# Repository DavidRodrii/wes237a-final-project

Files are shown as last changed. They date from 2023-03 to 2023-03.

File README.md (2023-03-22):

# wes237a-final-project
Final Project for WES237A class, UCSD WES Program, Winter 2023

# Contactless Health Monitoring System

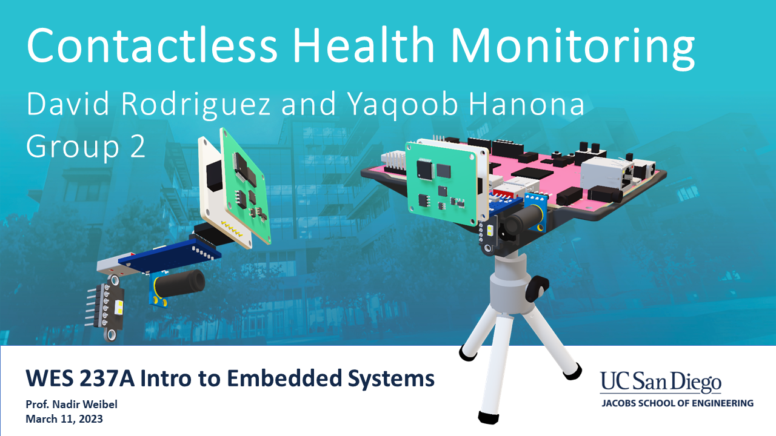
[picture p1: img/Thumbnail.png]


## What does the system do?

- Measures Patient Heart Rate
- Measures Patient Respiratory Activity 
- Measures Patient Temperature
- Detects Human Presence
- Detects Movement of Patient
- Detects Distance away from Patient
- Streams data values to AWS Cloud Server

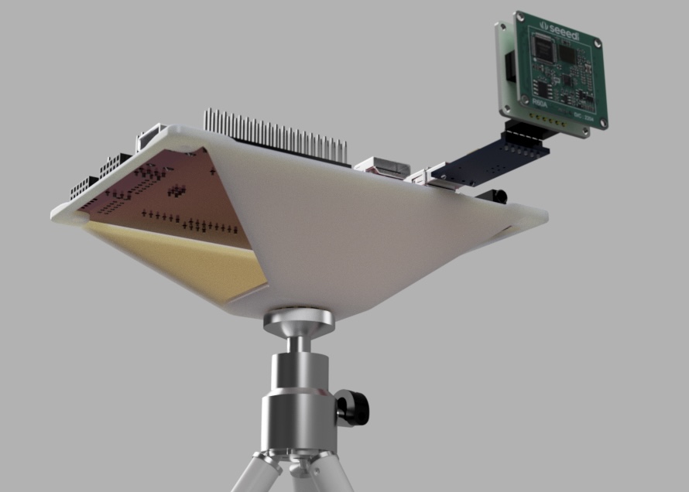
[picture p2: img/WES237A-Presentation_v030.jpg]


## How does it work?

- 60GHz Radar module relies on CWFM Doppler Analysis 
to determine small displacements associated with 
heart beats and breathing.

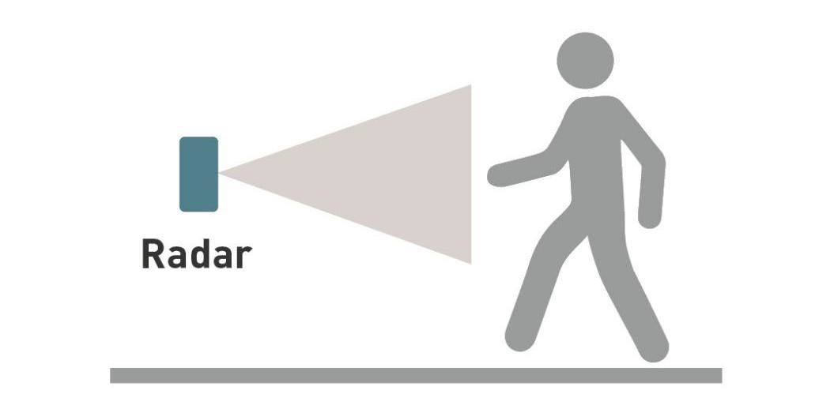
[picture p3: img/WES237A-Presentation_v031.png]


- Infrared Temperature Sensor measures light intensity 
for wavelengths associated with infrared heat signatures.

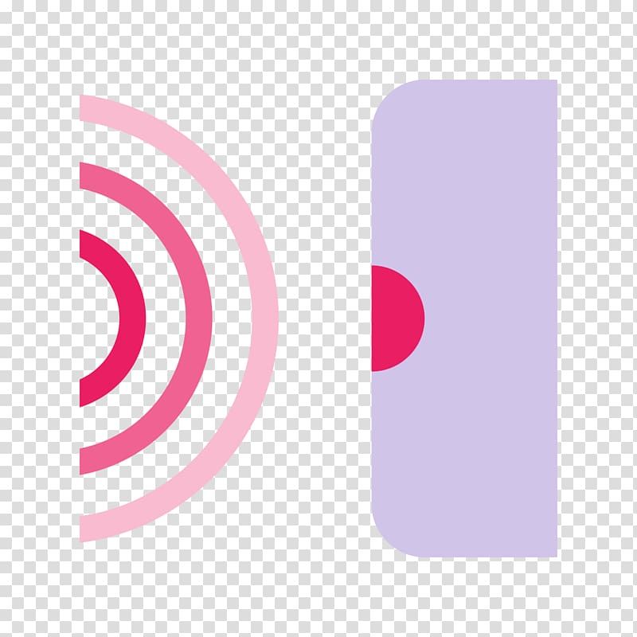
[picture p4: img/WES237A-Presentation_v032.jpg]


- ToF Distance Sensor emits infrared light pulses, records the time
taken to detect reflections, and correlates time to distance value.

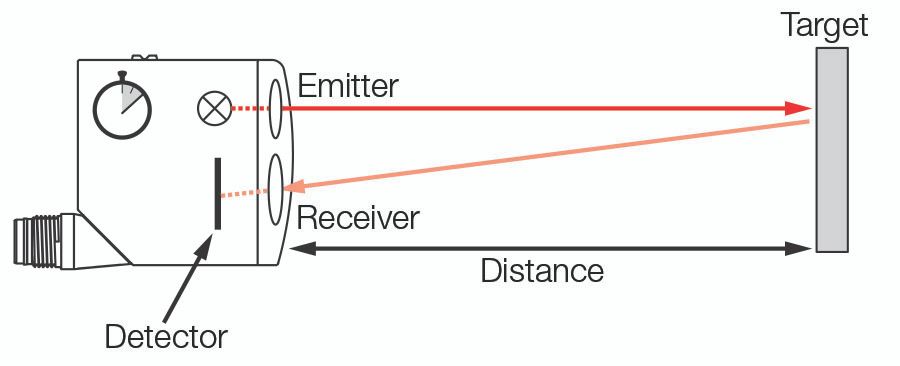
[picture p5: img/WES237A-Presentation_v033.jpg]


- PYNQ Z2 board joins sensor and networking functionality together 
to form a discrete health monitoring device



## Goals
- Create a functional contactless IoT health monitoring system using the Xilinx PYNQ Z2 board.

- Support ability to measure cardio, respiratory, and temperature data at a distance from a patient and produce health metrics visualizations in near real-time.

- Demonstrate and utilize concepts learned in WES 237A lab/lecture.

## WES 237A Topics Used in Project

* **I/O**: Uses PYNQ Microblaze for GPIO Digital Write controls for 
RGB LED Module

* **Multi-Tasking**: Uses Python Multiprocessing library to run multiple 
concurrent data collection and socket connection routines for each 
sensor

* **Networking**: Uses multiple UDP connections and TCP connections to 
send data to Server

* **Sensors/Actuators/IoT**: Uses I2C communication protocol to obtain 
data from VL53L1XV2 ToF Distance and MLX90614ESF Temperature 
sensors

# System Overview

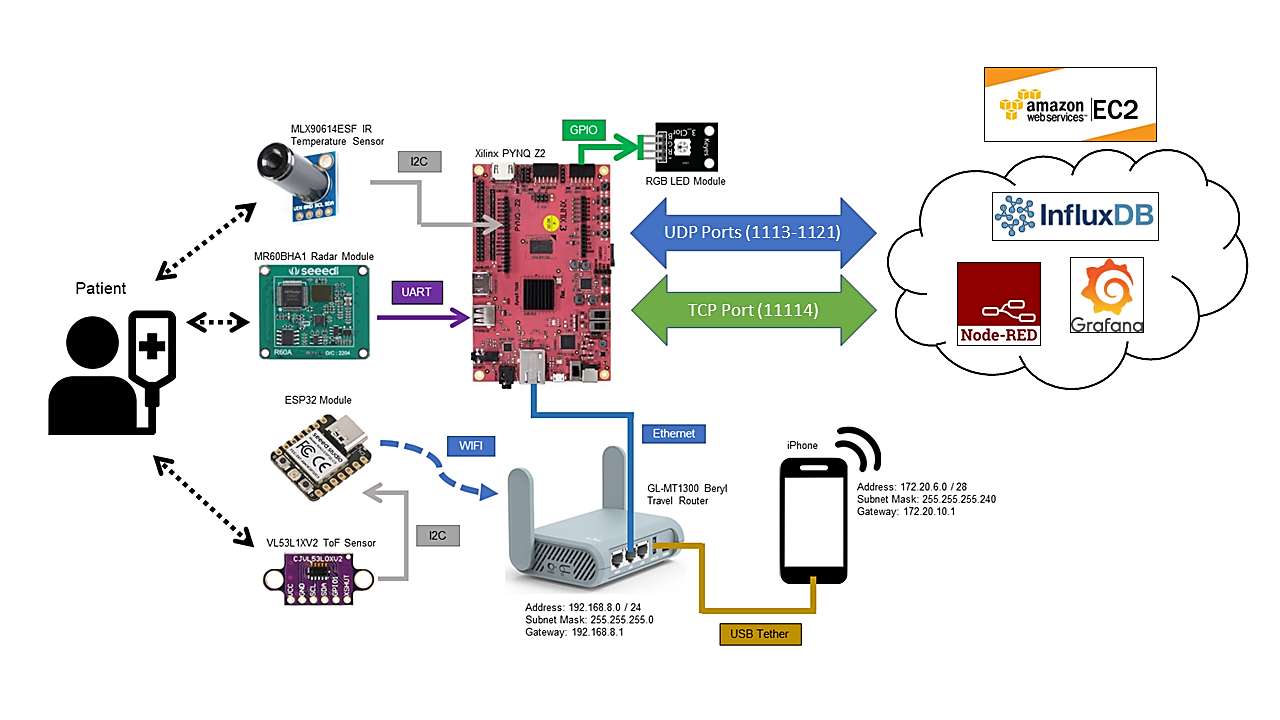
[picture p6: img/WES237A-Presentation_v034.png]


## Components Used

1. Xilinx PYNQ Z2 Board

2. Seeed Studio MR60BHA1 60 GHz mm Wave Sensor 
Onboard MCU processes radar signals and outputs UART messages containing cardio/respiratory health metrics

3. MLX90614 IR Temperature Sensor 
I2C and PWM compatible sensor
Supports measurements taken at 
	distances of ≤12cm

4. VL53L1X ToF Distance Sensor 
I2C compatible sensor
Supports accurate distance measurements 
	of up to 4 meters

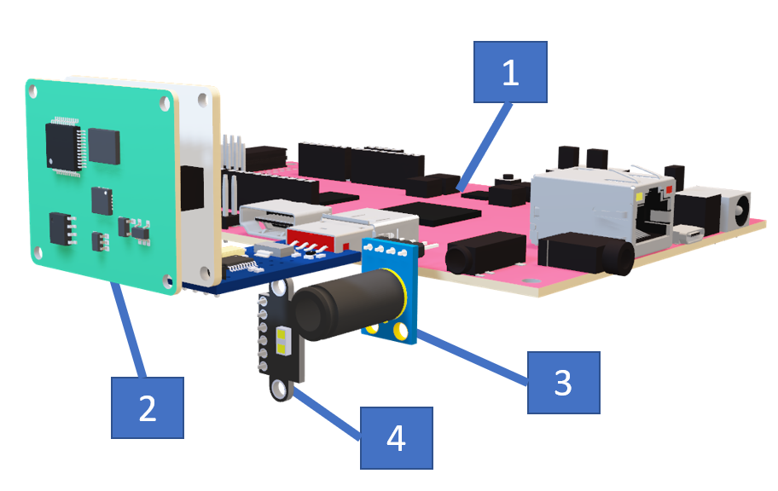
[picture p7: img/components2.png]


# Hardware Schematic
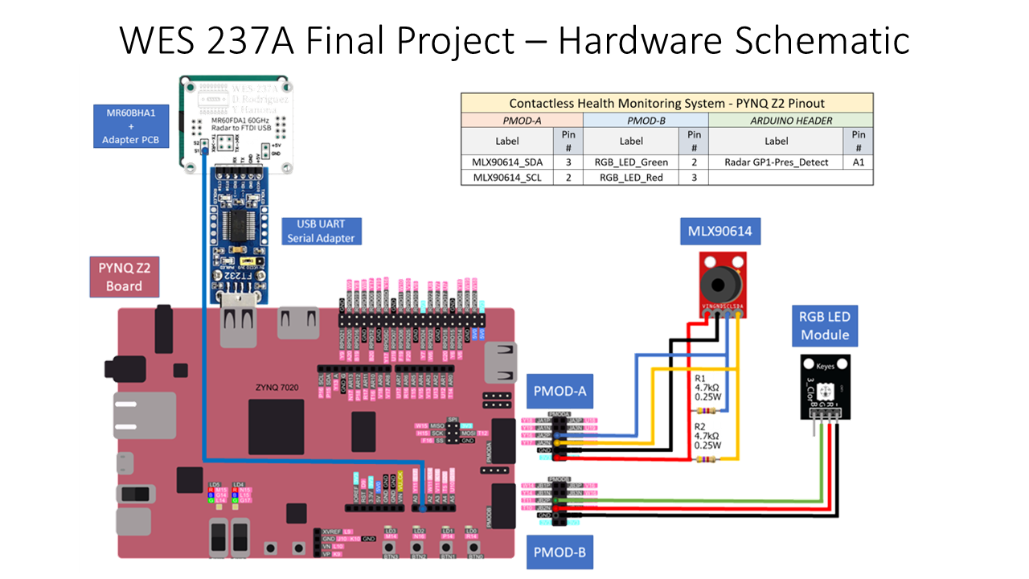
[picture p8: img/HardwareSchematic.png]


## Radar Sensor Assembly - _(Shown Left to Right)_

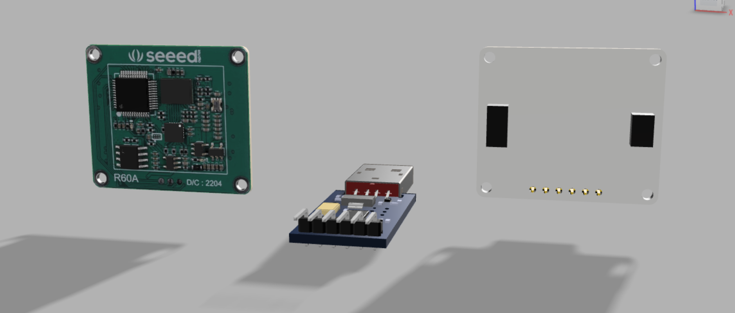
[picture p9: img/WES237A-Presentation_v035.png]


1. Seeed Studio MR60BHA1 60GHz mmWave 
Radar Sensor 

**Note**: MR60BHA1 GP1 Pin IO Pin reports human presence detection via digital signal output (3.3V = Presence Detected / 0V = No Presence Detected)

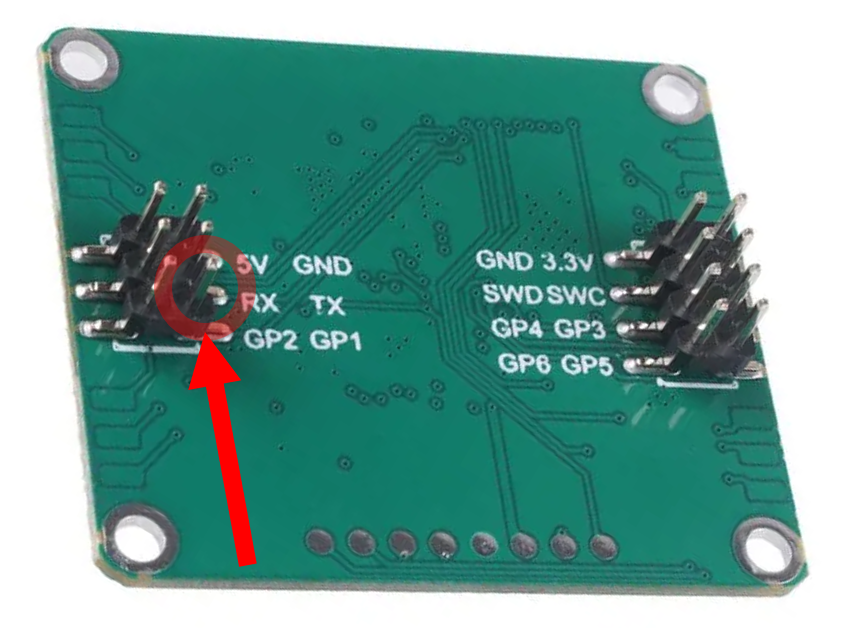
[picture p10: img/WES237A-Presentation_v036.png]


2. USB to UART FTDI Adapter

3. Custom PCB - MR60BHA1-to-USB Adapter

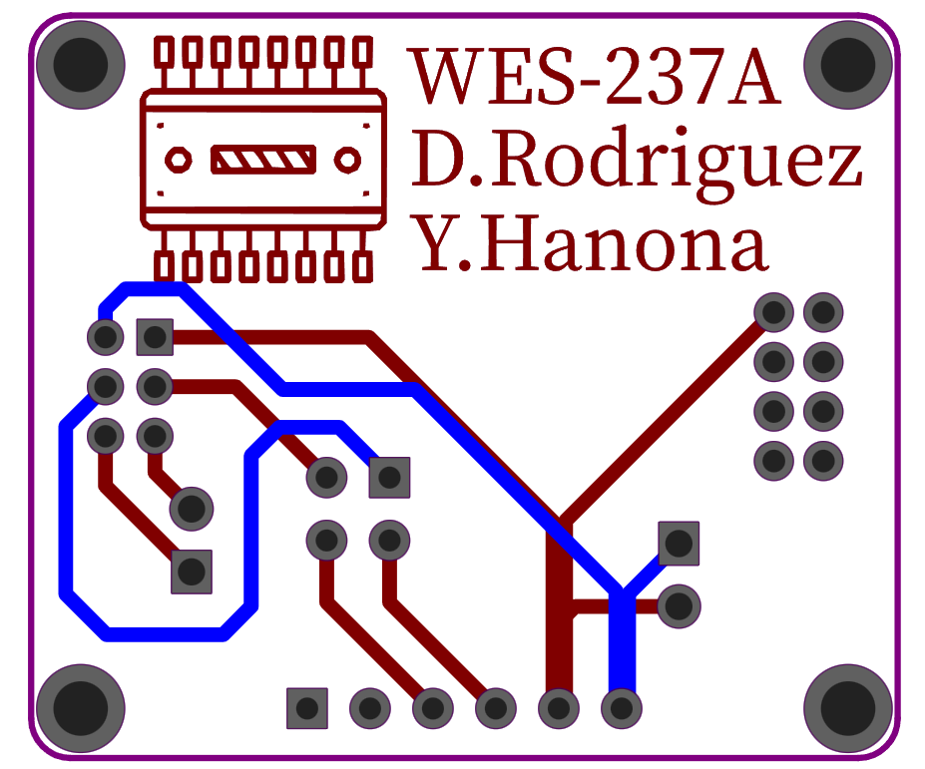
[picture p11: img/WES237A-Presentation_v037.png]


# AWS EC2 Server

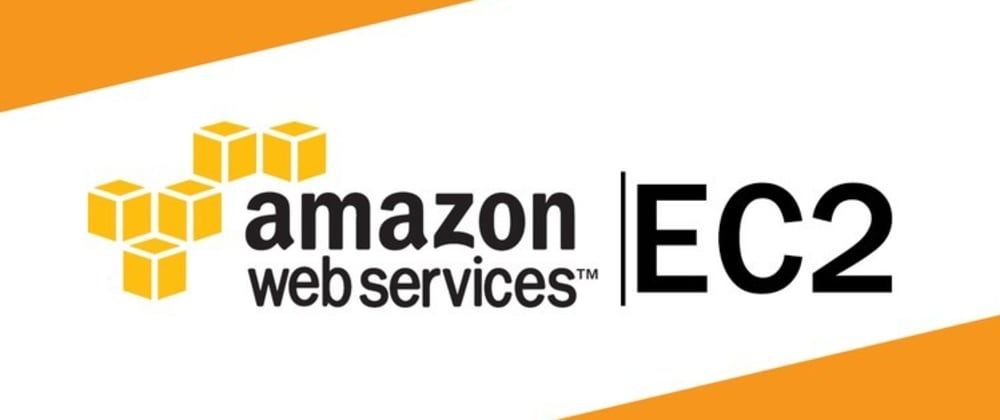
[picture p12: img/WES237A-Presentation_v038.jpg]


## Ubuntu 22.04

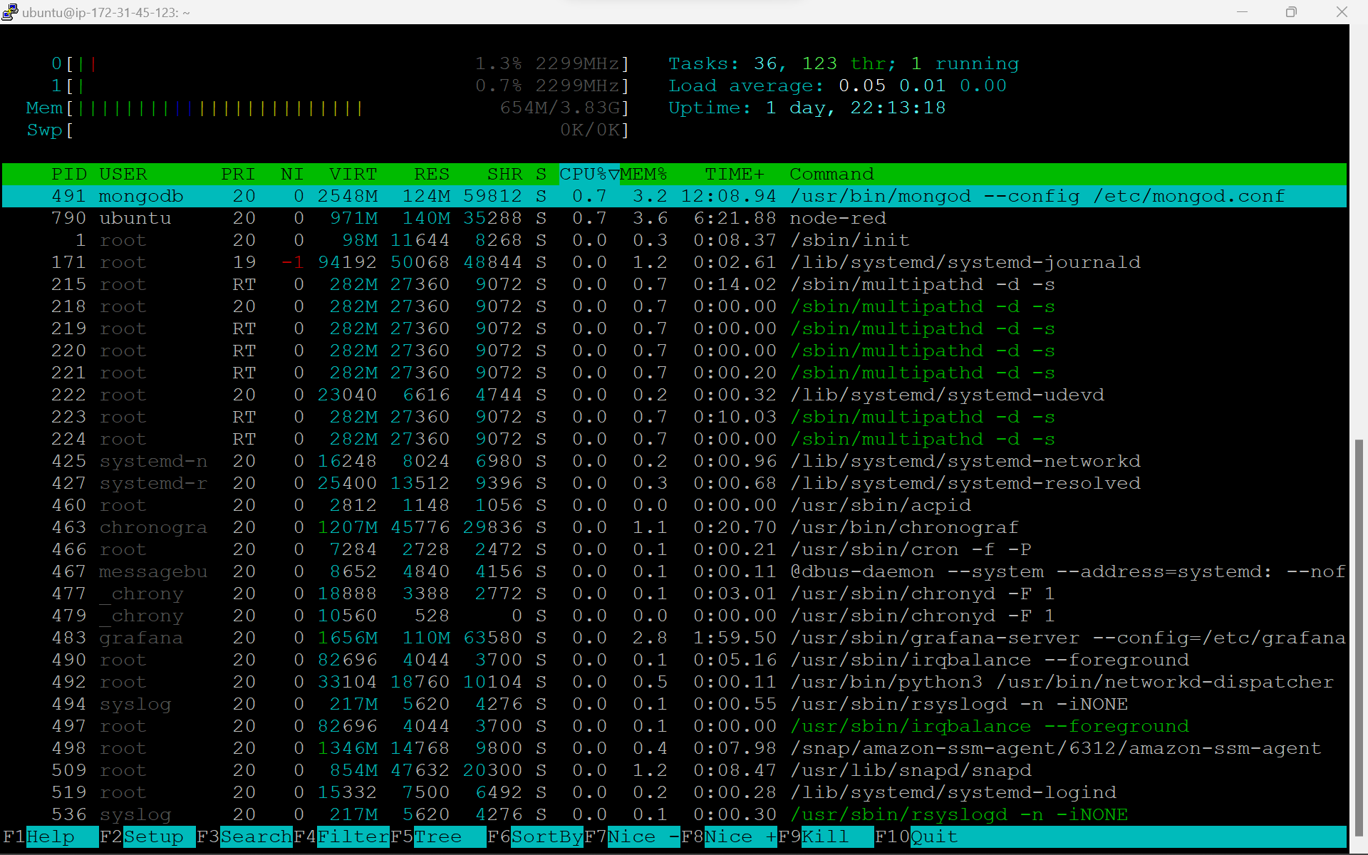
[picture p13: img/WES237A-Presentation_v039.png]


2 Cores vCPU
16 GB EBS Storage

__Services Hosted__:
- NodeRed
- InfluxDB
- Grafana

## NodeRed

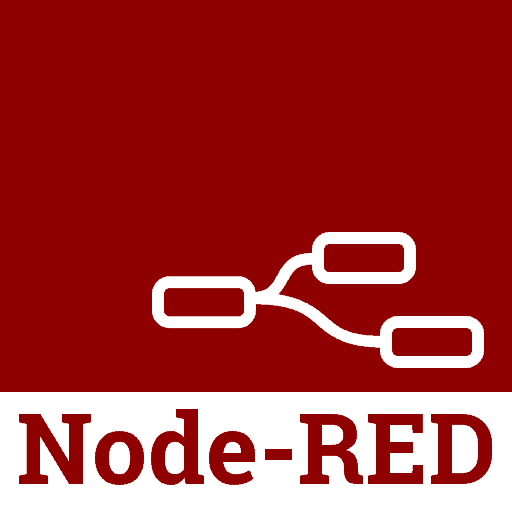
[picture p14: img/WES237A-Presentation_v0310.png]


NodeJS based Flow Process Manager Application that facilitates data flow and network communications using an assortment of node modules:

- Debug Nodes - output data payloads to debug console
- UDP and TCP Port Nodes - host port communications
- HTTP Endpoint Node - supports HTTP-POST requests
- JS Function Nodes - Parse Received Data
- Influxdb Nodes - Forward Data into Database

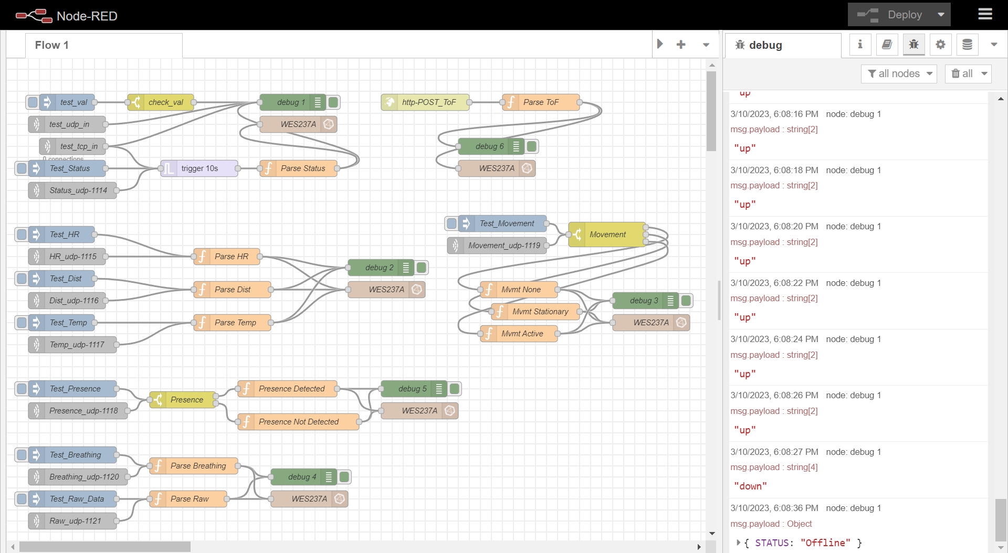
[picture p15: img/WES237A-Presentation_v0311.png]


## Influxdb

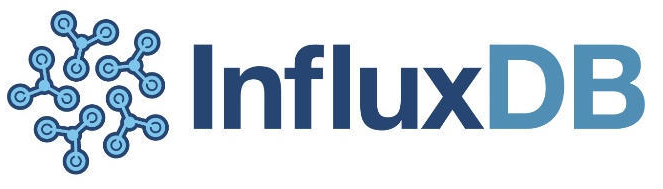
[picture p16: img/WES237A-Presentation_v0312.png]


Open-source Timeseries Database optimized for IoT applications

- Manages Storage of data entries
- Hosts Retention Policy to maintain long-term data accumulation
- Incorporates Timestamp for each data entry
- Accessed by Grafana Service to support dashboard visualization

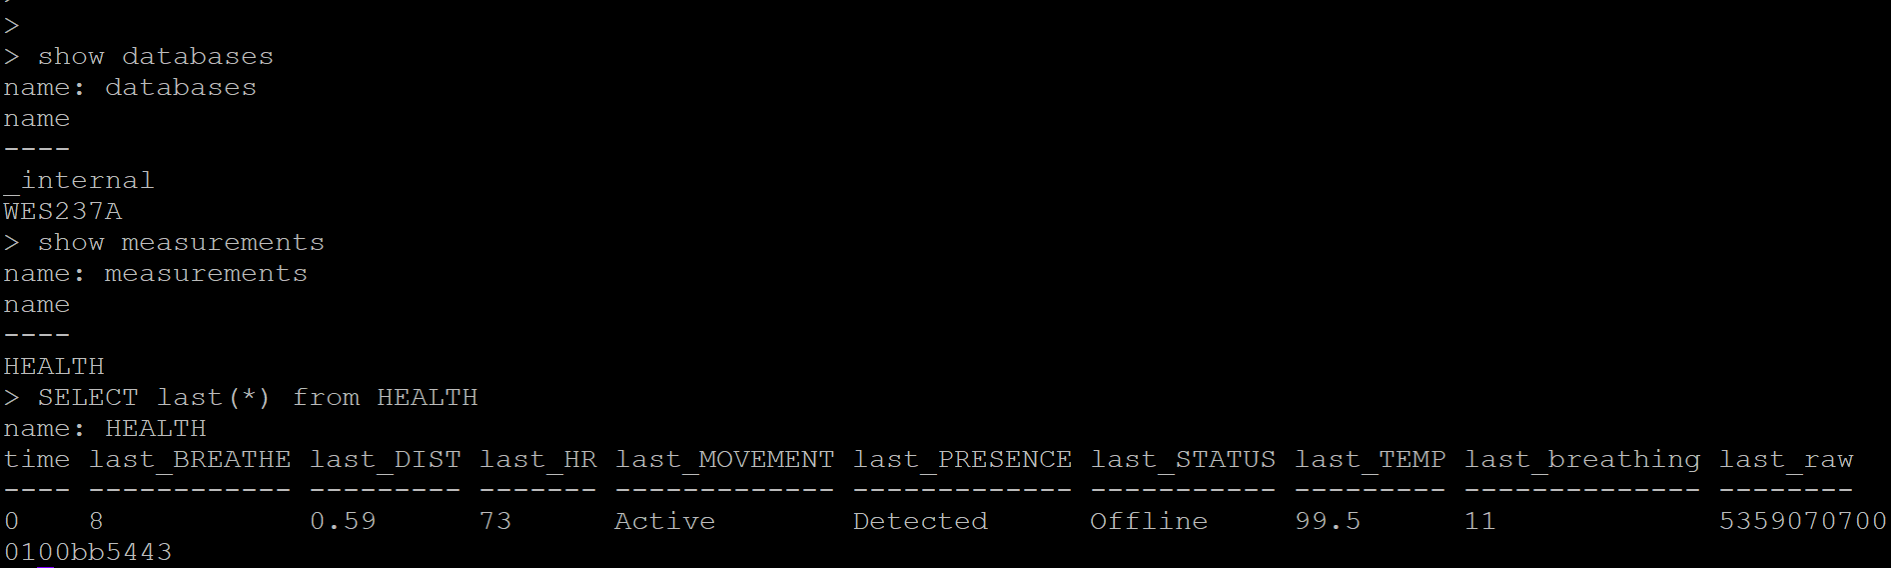
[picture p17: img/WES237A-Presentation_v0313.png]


## Grafana

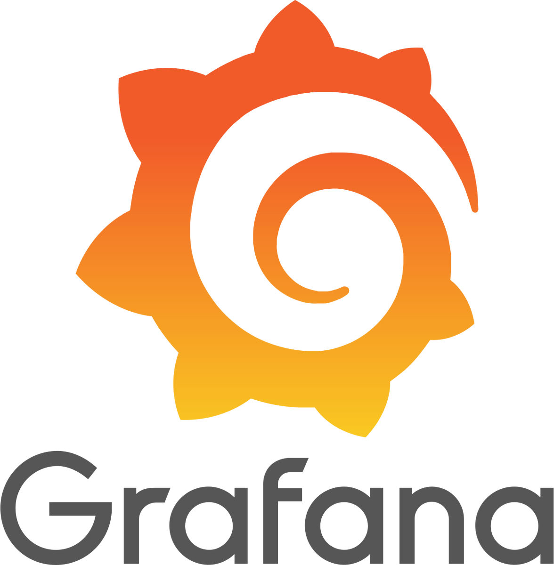
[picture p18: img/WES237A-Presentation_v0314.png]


Data Visualization GUI and Dashboard Application 
Reads and displays sensor data from Influxdb Database

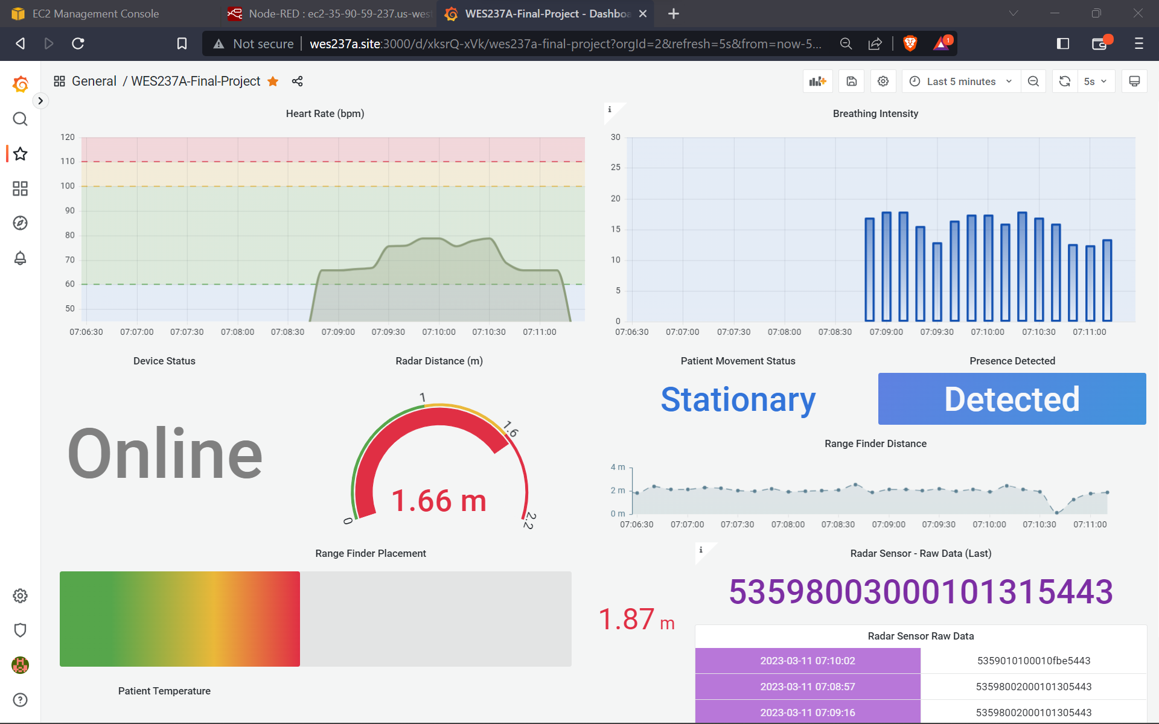
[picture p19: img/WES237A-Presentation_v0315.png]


# Contactless Health Monitor - Multiprocessing Flowchart 
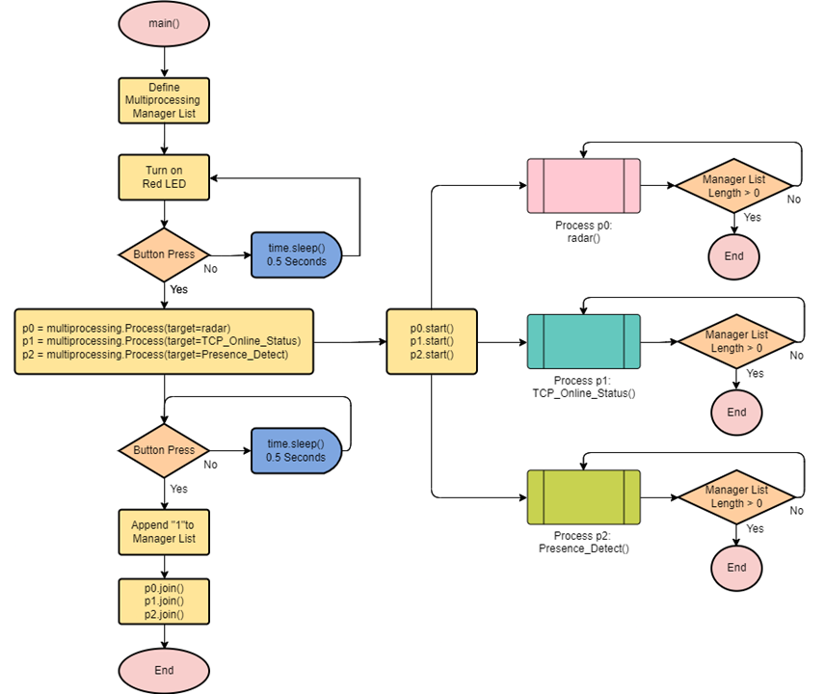
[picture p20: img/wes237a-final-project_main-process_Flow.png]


# Issues

- MLX90614 Temperature Sensor
I2C Reading Errors
‘Errno 9 Socket Error Bad File 
	Descriptor’ with multiprocess

- VL53L1X ToF Distance Sensor Integration
I2C Device Detection Problems

- MR60BHA1 60GHz Radar Sensor 
Intermittent performance of presence
	detection pin 
Serial message querying problems

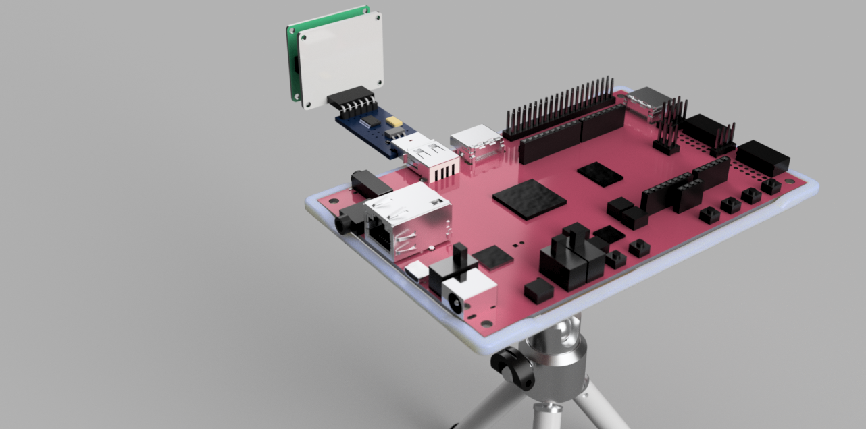
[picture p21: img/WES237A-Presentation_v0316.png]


# Next Steps

1. Spend more time troubleshooting I2C 
write/read steps on MLX90614 
Temperature Sensor

2. Integrate bidirectional communications 
between AWS Server and PYNQ Board

3. Introduce improvements in data filtering 
to improve accuracy

4. Have PYNQ board facilitate Push 
Notifications/Alerts based on health anomaly 
detection

5. Integrate IP Camera stream into Health 
Monitoring System

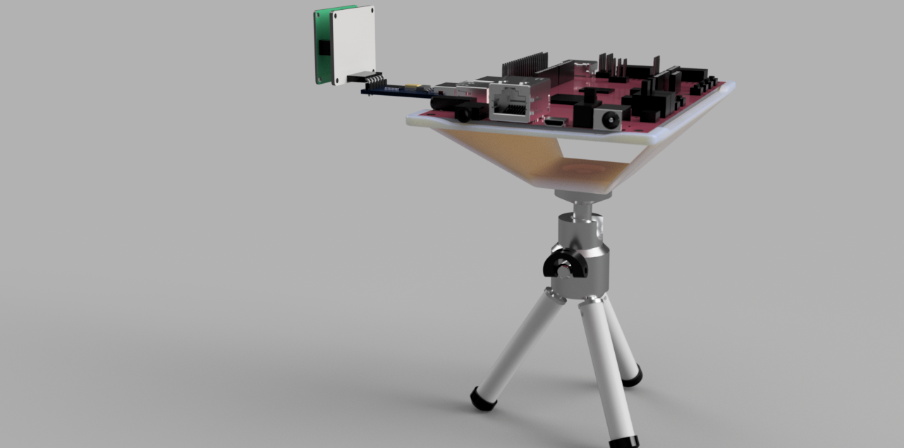
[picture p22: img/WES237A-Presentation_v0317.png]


# Contactless Health Monitoring System Demo

[www\.wes237a\.site:3000](https://www.youtube.com/watch?v=l8WjZGGD_Us)

1\. Login with credentials:

__Username__ : test
    
__Password__ : test

2\. Under  _Dashboards_ \, click on:

__WES237A\-Final\-Project__

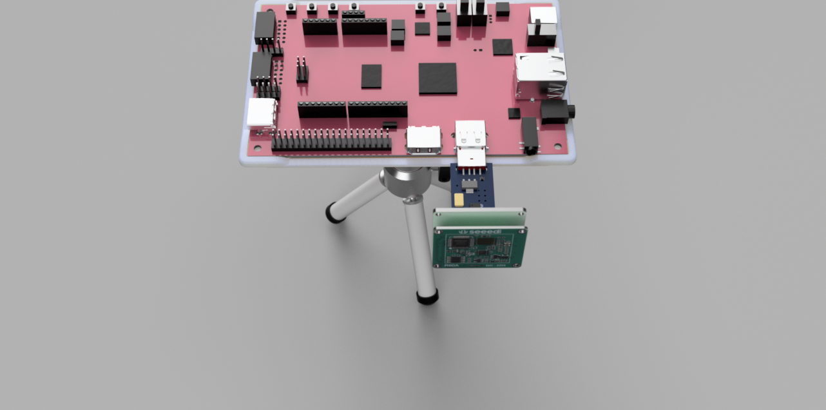
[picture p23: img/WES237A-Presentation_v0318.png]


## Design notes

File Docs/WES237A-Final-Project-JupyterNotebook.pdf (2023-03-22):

# WES-237A Final Project - Contactless Health Monitoring

### David Rodriguez & Yaqoob Hanona

### Group 2

### 11 March 2023

# Part 1: Importing Libraries

# Part 2: Microblaze Functions

In [1]:

import time
import serial
import socket

import subprocess
import multiprocessing
import pynq.lib.rgbled as rgbled
from pynq.overlays.base import BaseOverlay from pynq.lib import MicroblazeLibrary

from pynq.lib.arduino import Arduino_Analog from pynq.lib.arduino import ARDUINO_GROVE_A1
from pynq.lib.arduino import arduino_io

base = BaseOverlay("base.bit")
analog1 = Arduino_Analog(base.ARDUINO,ARDUINO_GROVE_A1)

btns = base.buttons[0:3] # Define list containing all built-in Buttons

In [2]:

%%microblaze base.PMODB
#include "gpio.h"

#include "pyprintf.h"

// Function to turn on/off a selected pin of PMODB int write_gpio(unsigned int pin, unsigned int val){ if (val > 1){
pyprintf("pin value must be 0 or 1");
}
gpio pin_out = gpio_open(pin); gpio_set_direction(pin_out, GPIO_OUT); gpio_write(pin_out, val);
}

// Reset GPIOS function - Resets all PMODB GPIOs (0-7) to Logic LOW void resetGPIOS() {
for (int pin=0; pin < 7; pin++){ // Iterate for all PMODB GPIO Pins write_gpio(pin, 0x00); // calling user defined function
}
}

void setGreen_HIGH(){
write_gpio(2, 0x01);
}

void setGreen_LOW(){
write_gpio(2, 0x00);
}

void setRed_HIGH(){
write_gpio(3, 0x01);
}

void setRed_LOW(){
write_gpio(3, 0x00);
}

# Part 3: Reset GPIOs

# Part 4: Defining Multiprocessing Processes

In [3]:

resetGPIOS() # Reset all GPIOs

In [4]:

setGreen_LOW() # Turn Green LED Off setRed_LOW() # Turn Red LED Off

In [5]:

# WES237A Final Project - Multiprocessing Processes

# Define Multiprocssing Manager List

manager = multiprocessing.Manager() seq_complete_list = manager.list()

setRed_HIGH() # Turn Red LED On = "Not Connected"

serverName = 'ec2-35-90-59-237.us-west-2.compute.amazonaws.com' # AWS Server Public DNS Domain testUDP_Port = 1113 # TEST UDP Port

clientPort = 11114 # TCP Client Port
port = 11115 # AWS Server TCP Listening Port

def Presence_Detect(): # Gets Presence Detection status from Radar Sensor GP1 Pin voltage, # then reports status to AWS Server via UDP Connection
serverName = 'ec2-35-90-59-237.us-west-2.compute.amazonaws.com' # AWS Server Public DNS UDPclientPort = 1118
clientSocket = socket.socket(family=socket.AF_INET, type=socket.SOCK_DGRAM)
while True:
analog1.read()
bits = analog1.read('raw')[1]
if bits >= 1000:
message = '1'
else:
message = '0'
time.sleep(0.05)
print('sending message: {}'.format(message))
# Connect to AWS Server UDP Port and Send Data clientSocket.sendto(message.encode(),(serverName, UDPclientPort)) time.sleep(9)

if len(seq_complete_list) > 0:
break
clientSocket.close()

def TCP_Online_Status(): # Report Online Status to AWS Server via TCP Connection # Create a TCP/IP socket
c_sock = socket.socket(socket.AF_INET, socket.SOCK_STREAM) print('Connecting PYNQ Client. . .')

# Connect Client

c_sock.connect((serverName, clientPort))
print('Connected to AWS Server!')

setRed_LOW() # Turn Red LED Off setGreen_HIGH() # Turn Green LED On

upMessage = 'up'
downMessage = 'down'

while True:
setGreen_HIGH()
time.sleep(8)
c_sock.send(upMessage.encode())

if len(seq_complete_list) > 0: setGreen_LOW()
setRed_HIGH()
# Send AWS TCP Server Offline Message c_sock.send(downMessage.encode()) break

# Disconnect from Client

c_sock.close()
print('Client Connection Socket Closed!')

def radar():
presence_detect = 0
while True:
serMsg = serial.Serial('/dev/ttyUSB0', 115200, timeout=2) #serMsg.flushInput()

# Read Radar Data from serial port

ch = serMsg.read(15).hex() # 15 bytes = max frame size for radar module

FRAME_HEADER = '5359'
END_OF_FRAME = '5443'

pt1 = ch.split(FRAME_HEADER)[1] pt2 = pt1.split(END_OF_FRAME)[0]

control_word = pt2[0:2]
command_word = pt2[2:4]
data_len = int(pt2[4:8])
data = pt2[8:(9+data_len)]

value_list = []

# Segment Data based on individual Bytes if data_len == 1:

value = int(data, base=16) value_list.append(value)
else:
for i in range(0, data_len):
value_segment = str(data[i]) + str(data[i+1]) value = int(value_segment, base=16) value_list.append(value)

# Heart Rate Value

if control_word == '85':
measurement_type = 'HR' # Heart Rate
if command_word == '02':
print('Heart Rate Values: ', value_list)
# Connect to AWS Server UDP Port and Send Data

clientSocket = socket.socket(family=socket.AF_INET, type=socket.SOCK_DGRAM) clientSocket.sendto(str(value_list[0]).encode(),(serverName, 1115)) clientSocket.close()
elif command_word == '05':
print('Heart Rate Waveform: ', value_list)

# Respiratory Intensity Value

if control_word == '81':
measurement_type = 'RM' # Respiratory Monitoring if command_word == '02':
print('Breathing Waveform: ', value_list)
# Connect to AWS Server UDP Port and Send Data

clientSocket = socket.socket(family=socket.AF_INET, type=socket.SOCK_DGRAM) clientSocket.sendto(str(value_list[0]).encode(),(serverName, 1120)) clientSocket.close()

elif command_word == '01':
print('Breathing Values: ', value_list)

# Human Presence Status, Distance, and Movement Info if control_word == '80':

measurement_type = 'HP' # Human Presence Info
movement = ''

# Human Presence Status

# NOTE: Although this is redundant to include since Presence_Detect() function fulfills the same purpose,

# this UDP transmission is only enacted if the Human Presence parameter is detected in the Raw Radar data stream if command_word == '01':

# Presence Status has changed

if value == 1:
print('Presence Detected!') message = '1'
else:
message = '0'
print('Presence Not Detected!')
clientSocket = socket.socket(family=socket.AF_INET, type=socket.SOCK_DGRAM) clientSocket.sendto(message.encode(),(serverName, 1118)) clientSocket.close()

# Human Movement Status

if command_word == '02':

# Part 5: Health Monitoring Program

print('Human Movement Info: ', value_list) if (int(value_list[0]) == 2):
movement = 'Active'
movement_status = '02'
elif (int(value_list[0]) == 1): movement = 'Stationary'
movement_status = '01'
else:
movement = 'None'
movement_status = '00'
if (len(value_list) == 0): movement = 'None'
movement_status = '00'
print('Movement Status: ', movement)
# Connect to AWS Server UDP Port and Send Data

clientSocket = socket.socket(family=socket.AF_INET, type=socket.SOCK_DGRAM) clientSocket.sendto(movement_status.encode(),(serverName, 1119)) clientSocket.close()

# Radar Distance Value

if command_word == '04':
print('Human Distance Info (cm): ', int(pt2[10:12],base=16))
# Connect to AWS Server UDP Port and Send Data

clientSocket = socket.socket(family=socket.AF_INET, type=socket.SOCK_DGRAM) clientSocket.sendto(str(int(pt2[10:12],base=16)).encode(),(serverName, 1116)) clientSocket.close()

# Send Raw Data from Radar Module

raw_data = FRAME_HEADER + pt2 + END_OF_FRAME
# Connect to AWS Server UDP Port and Send Raw Data

clientSocket = socket.socket(family=socket.AF_INET, type=socket.SOCK_DGRAM) clientSocket.sendto(str(raw_data).encode(),(serverName, 1121)) clientSocket.close()

serMsg.close()
time.sleep(0.005)

if len(seq_complete_list) > 0: break

In [6]:

# Define Main Program

def main():
setRed_HIGH() # Turn Red LED On

print('Press Button to initialize Health Monitoring System') while True:
if btns.read() != 0:
time.sleep(0.5)
# Initialize Processes

print('Initializing Processes') break

# Create 3 Processes

p0 = multiprocessing.Process(target=radar)
p1 = multiprocessing.Process(target=TCP_Online_Status) p2 = multiprocessing.Process(target=Presence_Detect)

# Start all Processes

p0.start()
p1.start()
p2.start()

while True:
if btns.read() != 0:
time.sleep(0.5)
seq_complete_list.append(1) setRed_LOW() # Red LED off
setGreen_LOW() # Green LED off
break

time.sleep(2) # Allow sufficient time for socket connections to close

# Join & Close all Processes

p0.join()
p0.close()

Press Button to initialize Health Monitoring System Initializing Processes
Connecting PYNQ Client. . .
sending message: 0
Connected to AWS Server!
Heart Rate Values: [81]
Human Distance Info (cm): 35 Human Movement Info: [1]
Movement Status: Stationary Human Distance Info (cm): 35 Human Movement Info: [2]
Movement Status: Active
Breathing Waveform: [9]
Heart Rate Values: [83]
Human Distance Info (cm): 35 sending message: 0
Heart Rate Values: [83]
Breathing Waveform: [9]
Human Distance Info (cm):
35Heart Rate Values: [83]
Human Distance Info (cm): 35 Heart Rate Values: [83]
Breathing Waveform:
[9]Human Distance Info (cm): 35sending message: 0
Heart Rate Values:
[83]Human Distance Info (cm): 35 Client Connection Socket Closed! Sequence Stopped!

p1.join()
p1.close()
p2.join()
p2.close()

setRed_LOW() # Red LED off setGreen_LOW() # Green LED off

print('Sequence Stopped!')

if __name__ == '__main__':
main()

In [ ]:

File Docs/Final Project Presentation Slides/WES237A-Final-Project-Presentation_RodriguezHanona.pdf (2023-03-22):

# Contactless Health Monitoring

## David Rodriguez and Yaqoob Hanona

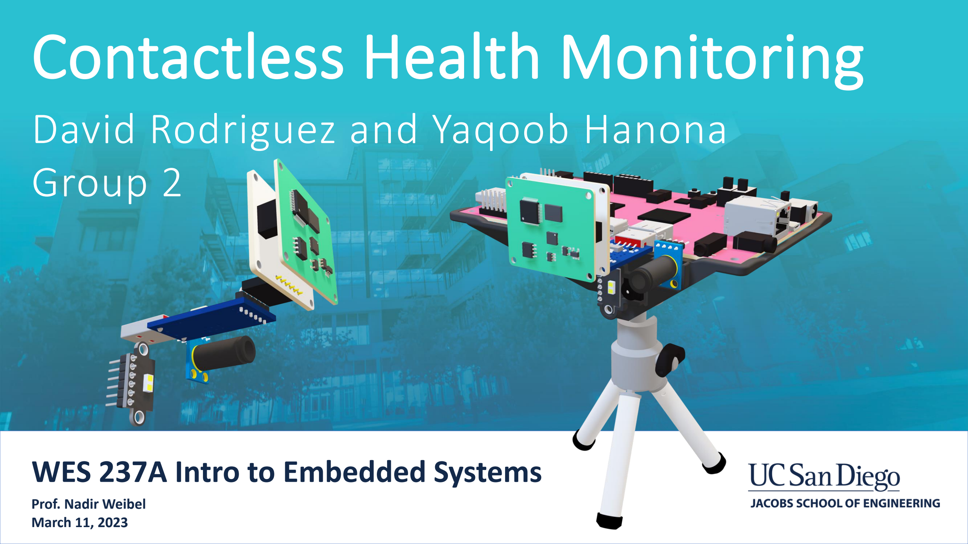
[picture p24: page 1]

Prof. Nadir Weibel
March 11, 2023

WES 237A Intro to Embedded Systems

## Group 2

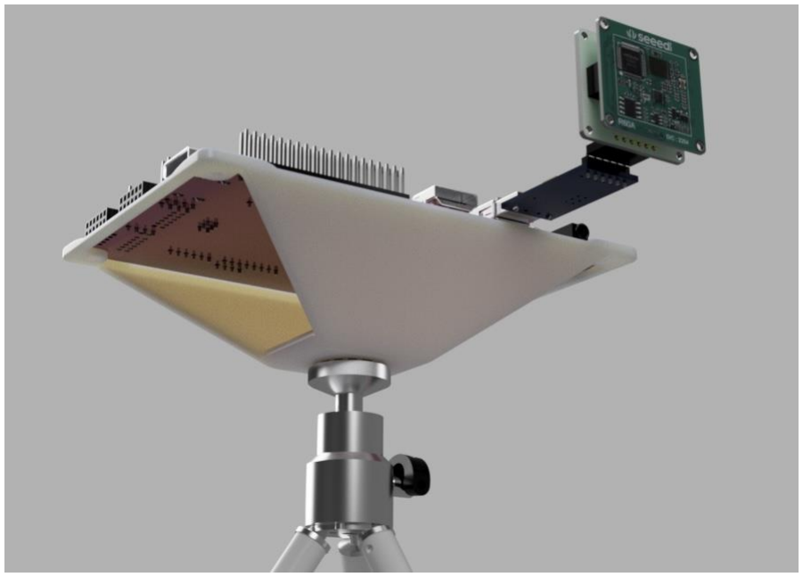
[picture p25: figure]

COMPUTER SCIENCE AND ENGINEERING | WES 237A Winter 2023 – Group 2

## CONTACTLESS HEALTH MONITORING SYSTEM

- What does the system do?
- Measures Patient Heart Rate
- Measures Patient Respiratory
Activity
- Measures Patient Temperature
- Detects Human Presence
- Detects Movement of Patient
- Detects Distance away from Patient
- Streams data values to AWS Cloud Server

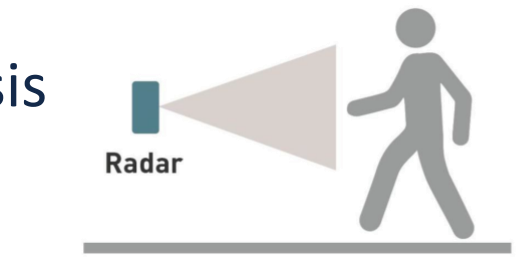
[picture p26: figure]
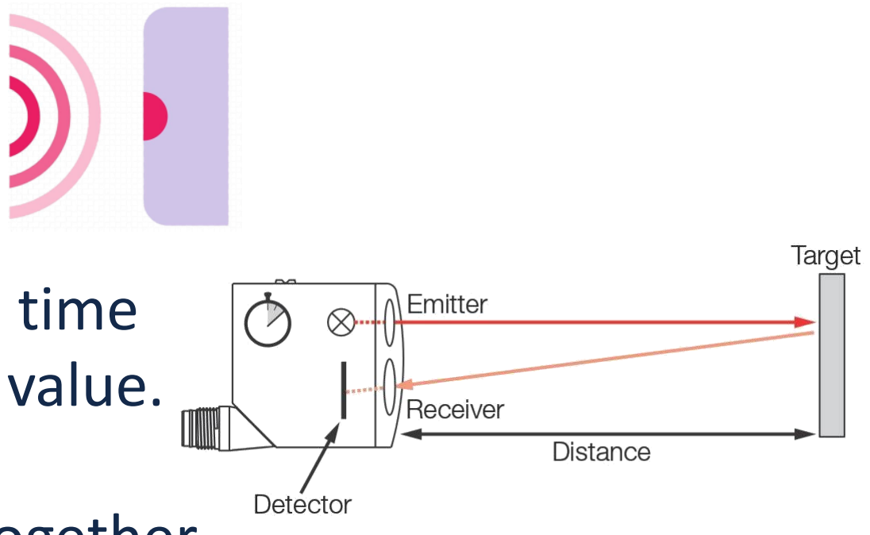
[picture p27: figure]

COMPUTER SCIENCE AND ENGINEERING | WES 237A Winter 2023 – Group 2

## CONTACTLESS HEALTH MONITORING SYSTEM

- How does it work?

60GHz Radar module relies on CWFM Doppler Analysis
to determine small displacements associated with heart beats and breathing.

Infrared Temperature Sensor measures light intensity
for wavelengths associated with infrared heat signatures.

ToF Distance Sensor emits infrared light pulses, records the time taken to detect reflections, and correlates time to distance value.

PYNQ Z2 board joins sensor and networking functionality together to form a discrete health monitoring device

COMPUTER SCIENCE AND ENGINEERING | WES 237A Winter 2023 – Group 2

## CONTACTLESS HEALTH MONITORING SYSTEM

- Goals
- Create a functional contactless IoT health monitoring system using the Xilinx PYNQ Z2 board.
- Able to measure cardio, respiratory, and temperature data at a distance from a patient and produce health metrics visualizations in near real-time.
- Able to use concepts learned in WES 237A lab/lecture.

COMPUTER SCIENCE AND ENGINEERING | WES 237A Winter 2023 – Group 2

## WES 237A TOPICS USED IN PROJECT

- I/O: Uses PYNQ Microblaze for GPIO Digital Write controls for
RGB LED Module
- Multi-Tasking: Uses Python Multiprocessing library to run multiple concurrent data collection and socket connection routines for each sensor
- Networking: Uses multiple UDP connections and TCP connections to send data to Server
- Sensors/Actuators/IoT: Uses I2C communication protocol to obtain data from VL53L1XV2 ToF Distance and MLX90614ESF Temperature sensors

## SYSTEM OVERVIEW

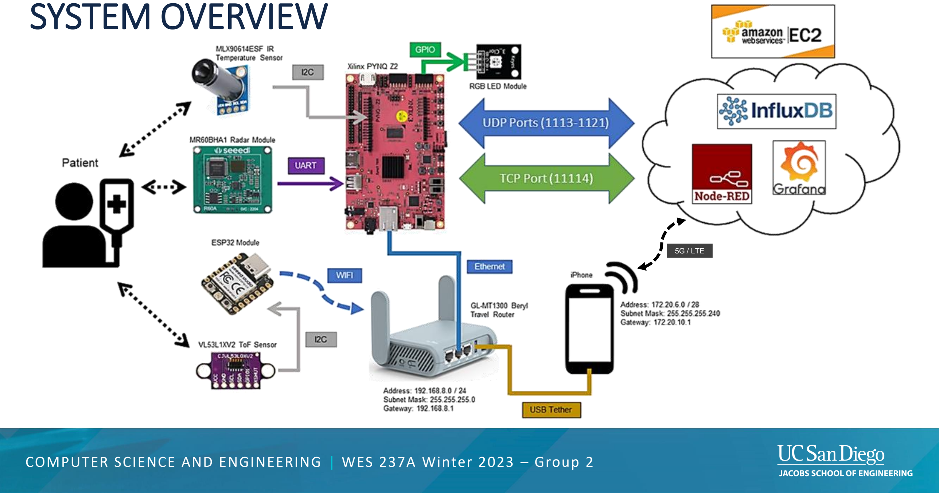
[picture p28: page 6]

COMPUTER SCIENCE AND ENGINEERING | WES 237A Winter 2023 – Group 2

5G / LTE

# COMPONENTS USED

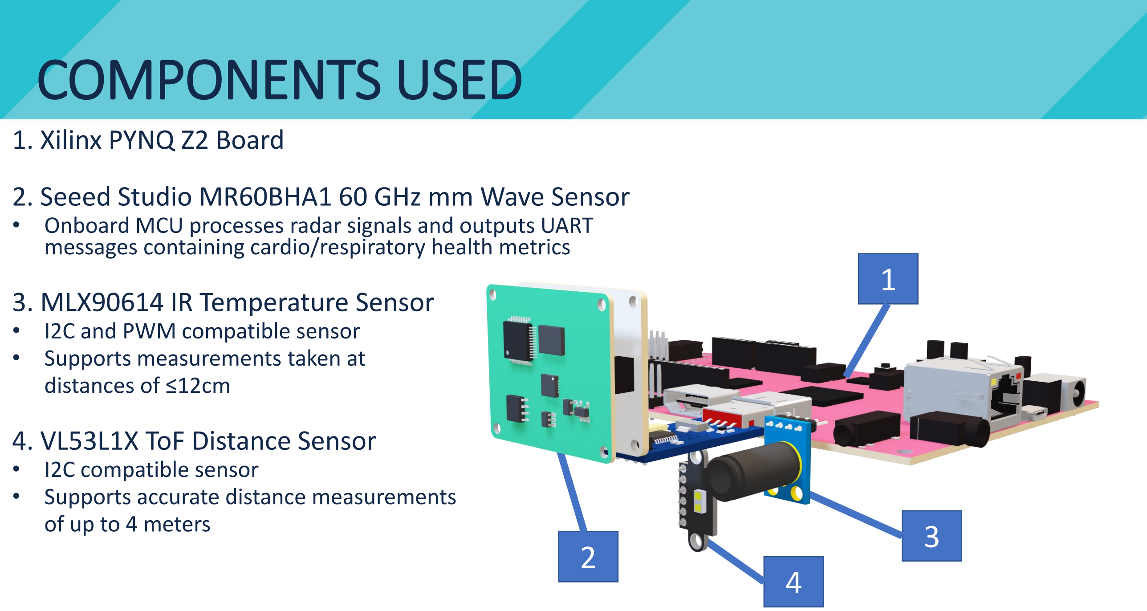
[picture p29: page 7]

1. Xilinx PYNQ Z2 Board
2. Seeed Studio MR60BHA1 60 GHz mm Wave Sensor
- Onboard MCU processes radar signals and outputs UART messages containing cardio/respiratory health metrics
3. MLX90614 IR Temperature Sensor
- I2C and PWM compatible sensor
- Supports measurements taken at
distances of ≤12cm
4. VL53L1X ToF Distance Sensor
- I2C compatible sensor
- Supports accurate distance measurements of up to 4 meters
2

3
4

1

# RADAR SENSOR ASSEMBLY

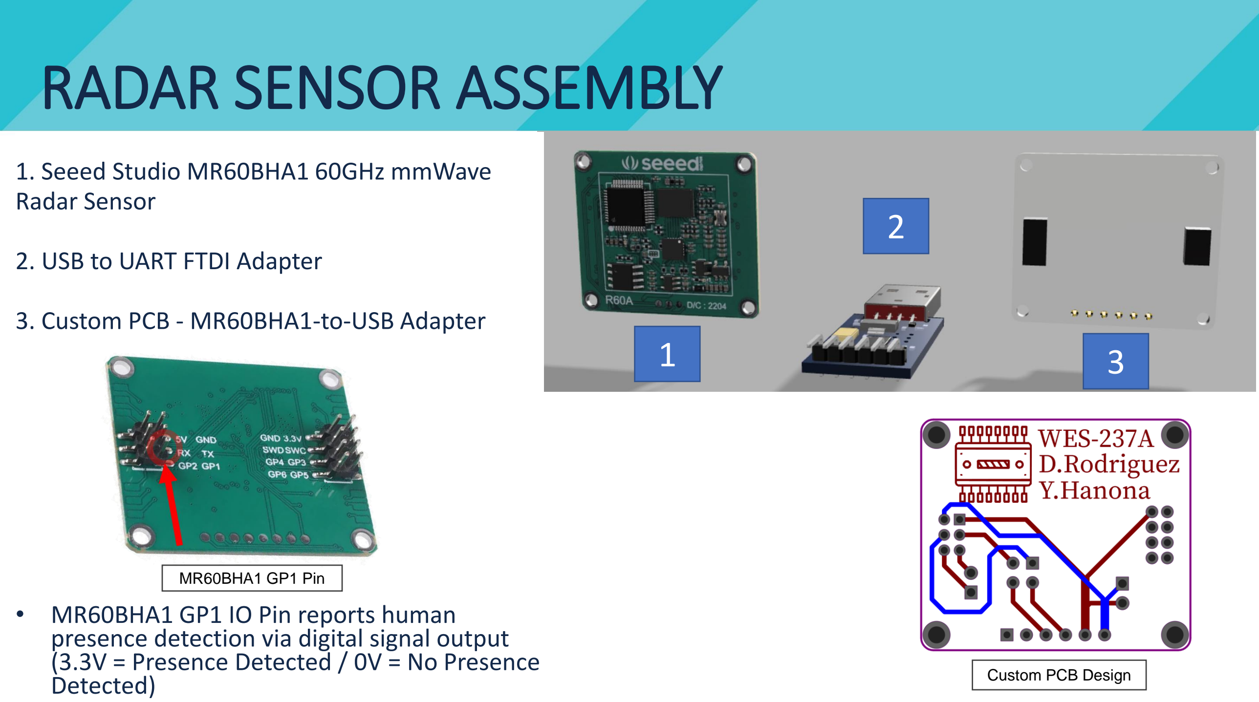
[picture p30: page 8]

1. Seeed Studio MR60BHA1 60GHz mmWave Radar Sensor
2. USB to UART FTDI Adapter
3. Custom PCB - MR60BHA1-to-USB Adapter
- MR60BHA1 GP1 IO Pin reports human presence detection via digital signal output (3.3V = Presence Detected / 0V = No Presence Detected)

1

2

3

MR60BHA1 GP1 Pin

Custom PCB Design

# AWS EC2 SERVER

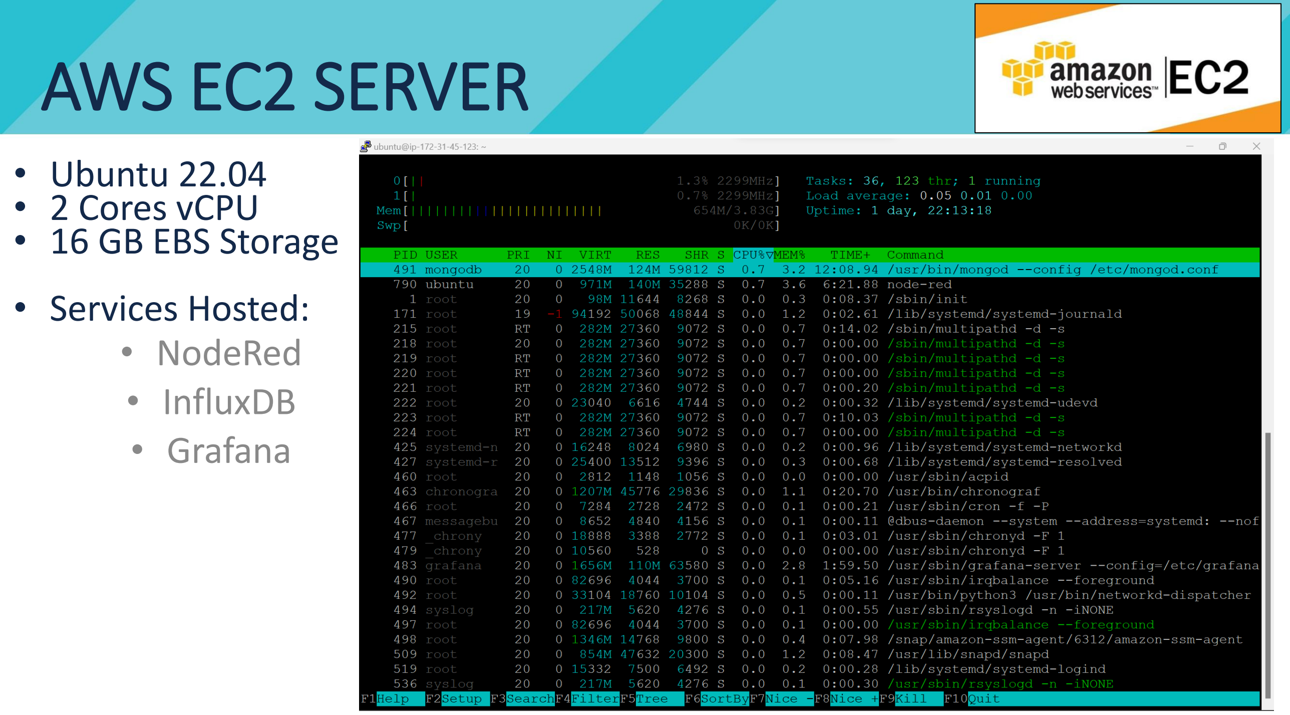
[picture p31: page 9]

- Ubuntu 22.04
- 2 Cores vCPU
- 16 GB EBS Storage
- Services Hosted:
- NodeRed
- InfluxDB
- Grafana

# AWS EC2 SERVER: NODERED

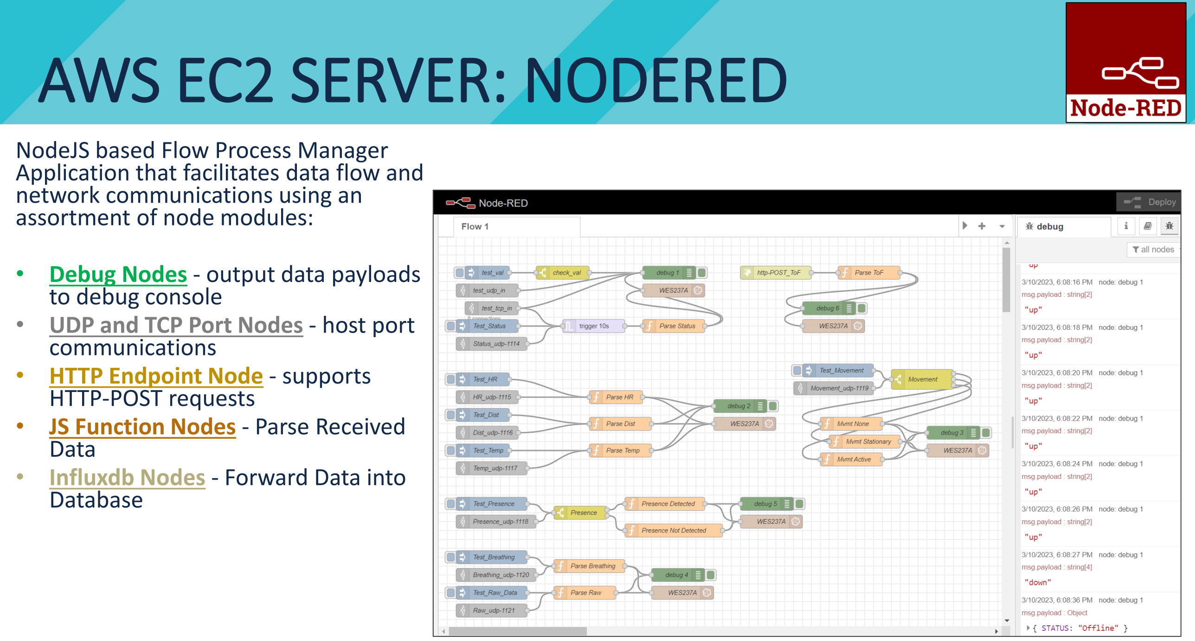
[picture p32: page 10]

NodeJS based Flow Process Manager Application that facilitates data flow and network communications using an assortment of node modules:

- Debug Nodes - output data payloads to debug console
- UDP and TCP Port Nodes - host port communications
- HTTP Endpoint Node - supports HTTP-POST requests
- JS Function Nodes - Parse Received Data
- Influxdb Nodes - Forward Data into Database

# AWS EC2 SERVER: INFLUXDB

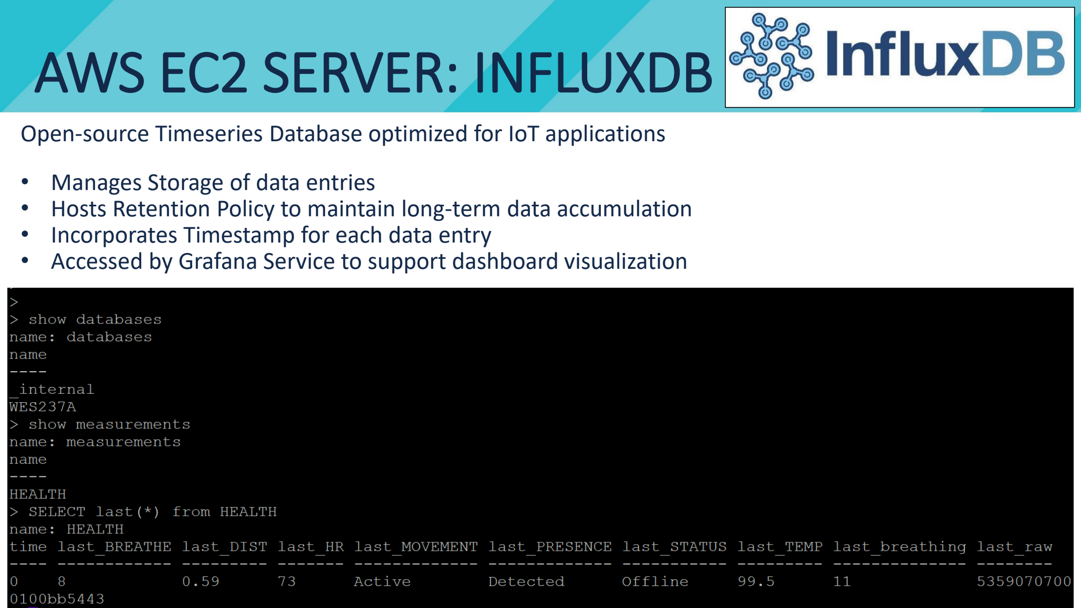
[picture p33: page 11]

Open-source Timeseries Database optimized for IoT applications

- Manages Storage of data entries
- Hosts Retention Policy to maintain long-term data accumulation
- Incorporates Timestamp for each data entry
- Accessed by Grafana Service to support dashboard visualization

# AWS EC2 SERVER: GRAFANA

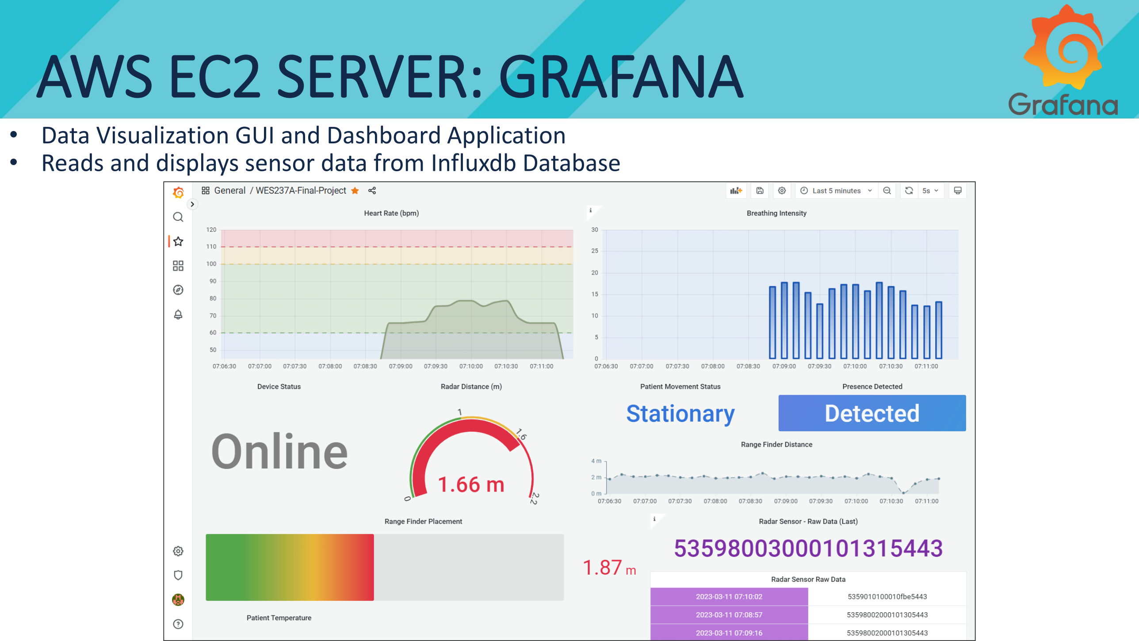
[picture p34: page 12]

- Data Visualization GUI and Dashboard Application
- Reads and displays sensor data from Influxdb Database

# ISSUES

MLX90614 Temperature Sensor
- I2C Reading Errors

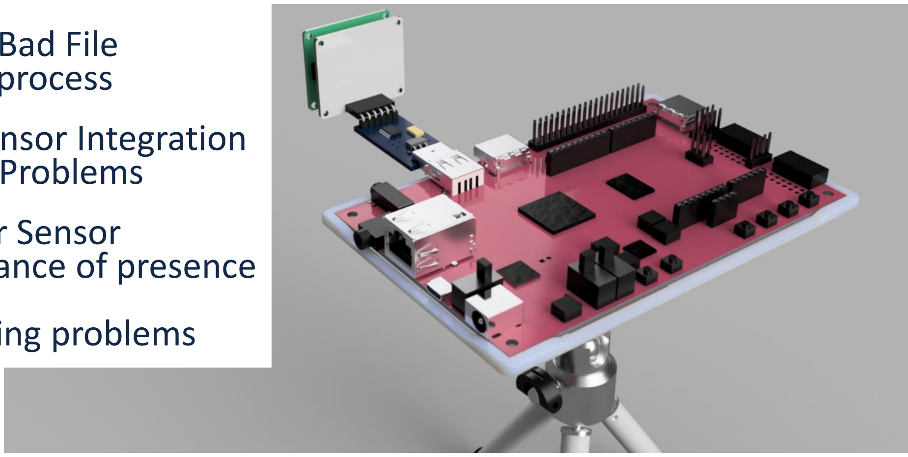
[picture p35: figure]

- ‘Errno 9 Socket Error Bad File Descriptor’ with multiprocess VL53L1X ToF Distance Sensor Integration
- I2C Device Detection Problems MR60BHA1 60GHz Radar Sensor
- Intermittent performance of presence detection pin
- Serial message querying problems

# NEXT STEPS

1. Spend more time troubleshooting I2C write/read steps on MLX90614 Temperature Sensor

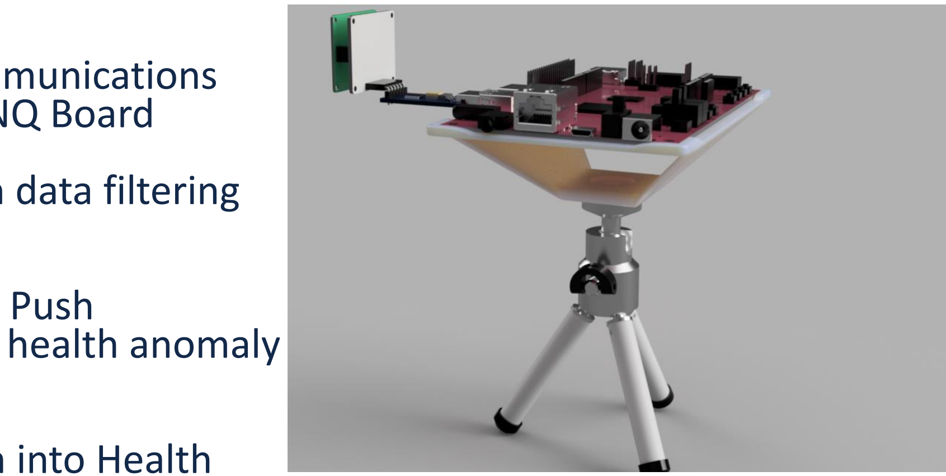
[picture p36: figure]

2. Integrate bidirectional communications between AWS Server and PYNQ Board
3. Introduce improvements in data filtering to improve accuracy
4. Have PYNQ board facilitate Push Notifications/Alerts based on health anomaly detection
5. Integrate IP Camera stream into Health Monitoring System

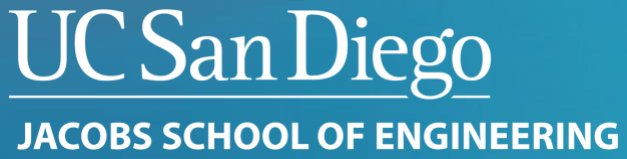
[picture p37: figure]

March 11, 2023

### www.wes237a.site:3000

1. Login with credentials:
Username: test
Password: test
2. Under Dashboards, click on: WES237A-Final-Project

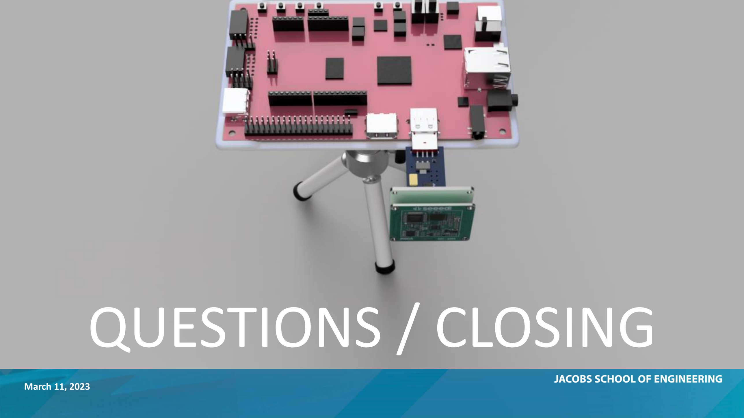
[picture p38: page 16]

March 11, 2023

# QUESTIONS / CLOSING

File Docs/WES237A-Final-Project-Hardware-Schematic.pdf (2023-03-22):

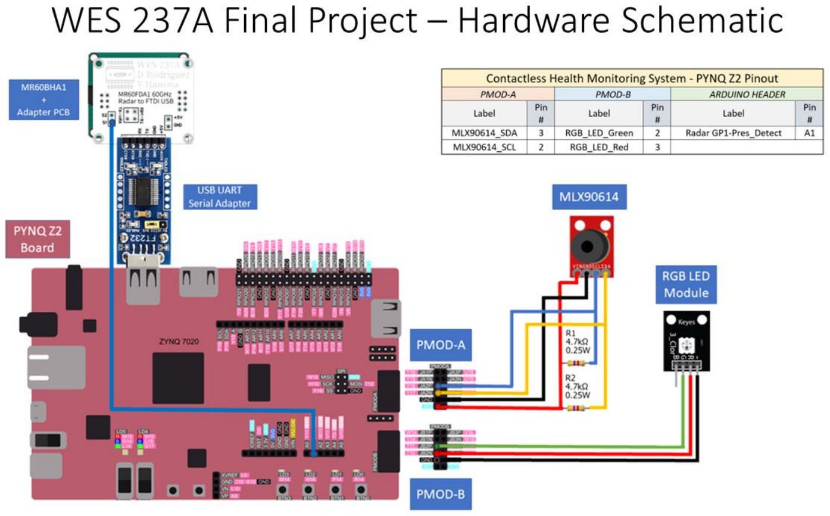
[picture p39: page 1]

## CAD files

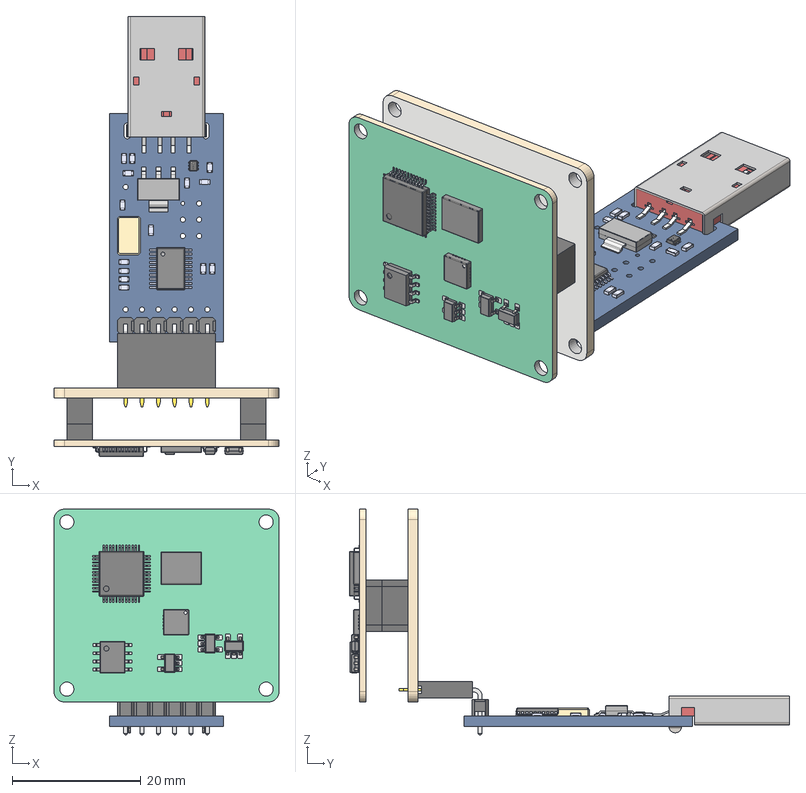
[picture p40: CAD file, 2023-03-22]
CAD Design Files & 3D Models/stp/USB-Stick-Assembly-MR60FDA1-60GHz-Radar.step
35.0 x 68.5 x 35.1 mm
2.0mm Headers (M)
Open_CASCADE_STEP_translator_6.8_13.2.1.step_Varsaylan
Open_CASCADE_STEP_translator_6.8_13.1.step_Varsay lan
Leader.step_Varsaylan x 24
Leader-0.step_Varsaylan x 24
SOIC-8 v1
sot23-5 v3 x 3
2.0mm Headers (F)
female-PBS-6 v1
STM32F070-minidongle

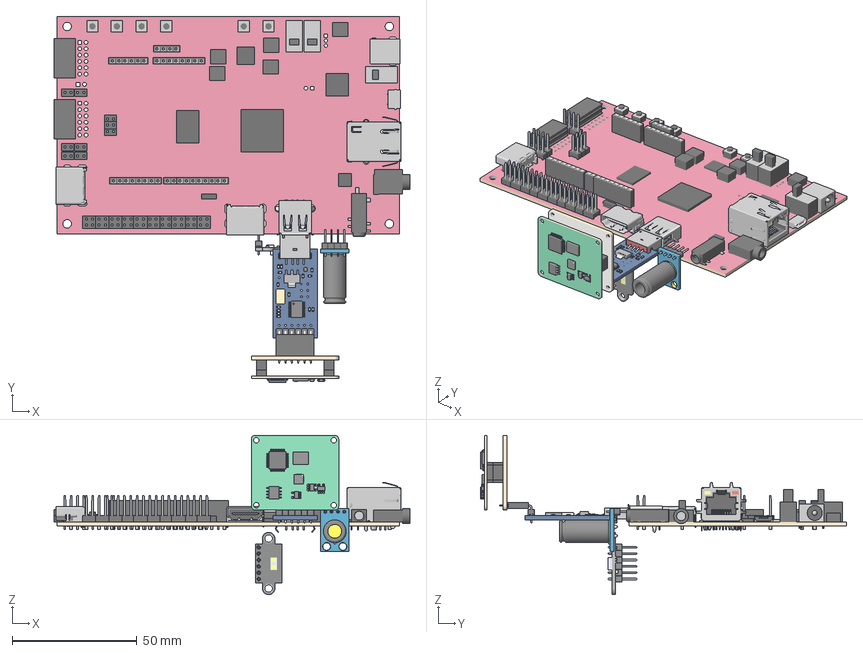
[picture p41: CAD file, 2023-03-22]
CAD Design Files & 3D Models/3mf/PYNQ&Components.3mf
142.5 x 146.5 x 63.8 mm

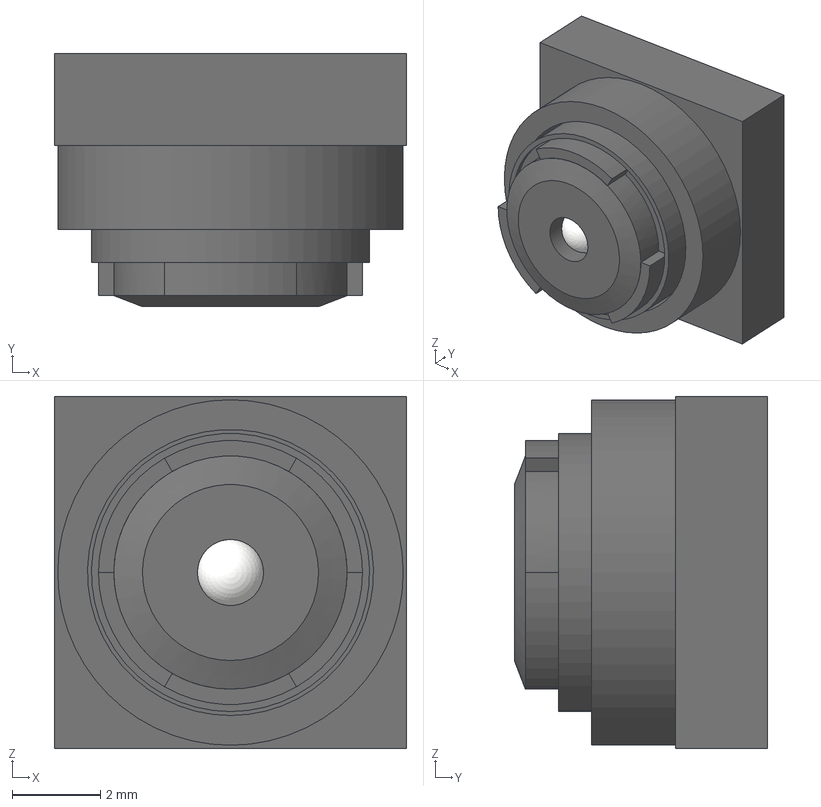
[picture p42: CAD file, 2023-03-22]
CAD Design Files & 3D Models/stp/OV2640 v2 v4.step
8.00 x 5.76 x 8.00 mm

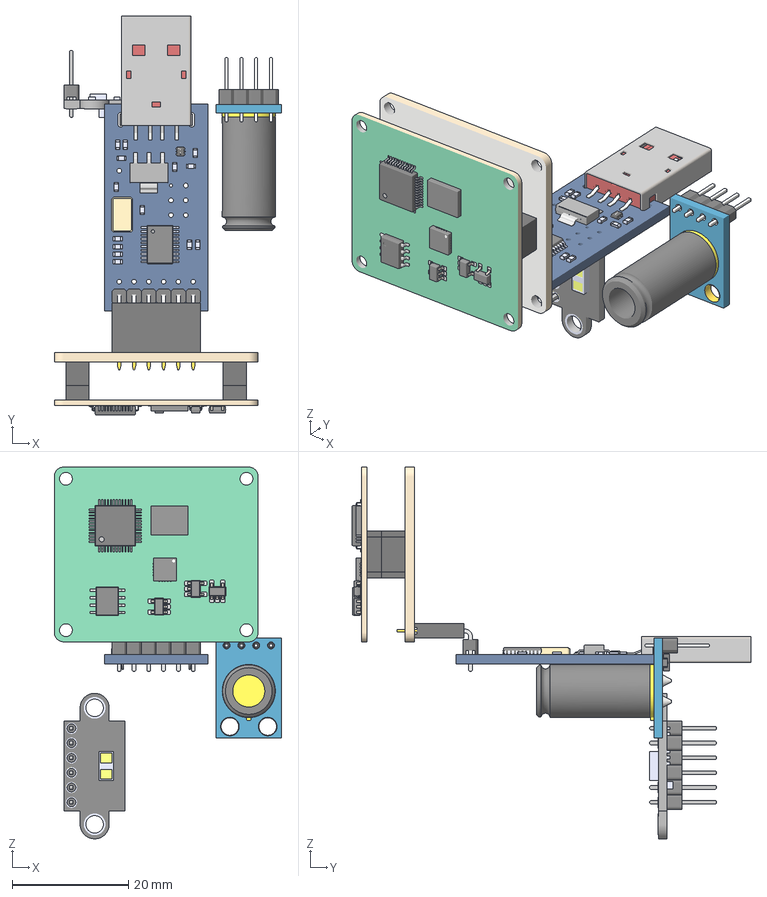
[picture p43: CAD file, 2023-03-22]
CAD Design Files & 3D Models/3mf/Sensor-Components.3mf
39.0 x 68.5 x 63.8 mm

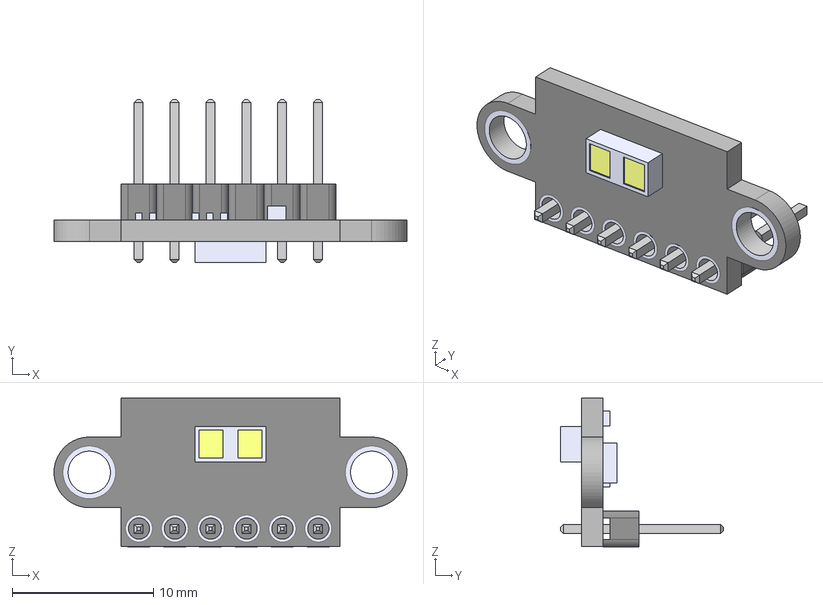
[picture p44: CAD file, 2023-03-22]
CAD Design Files & 3D Models/stp/VL53l1X v8.step
25.0 x 11.5 x 10.5 mm
Pino
Base
Pino001
Base001
Pino002
Base002
Pino003
Base003
Pino004
Base004
Pino005
Base005

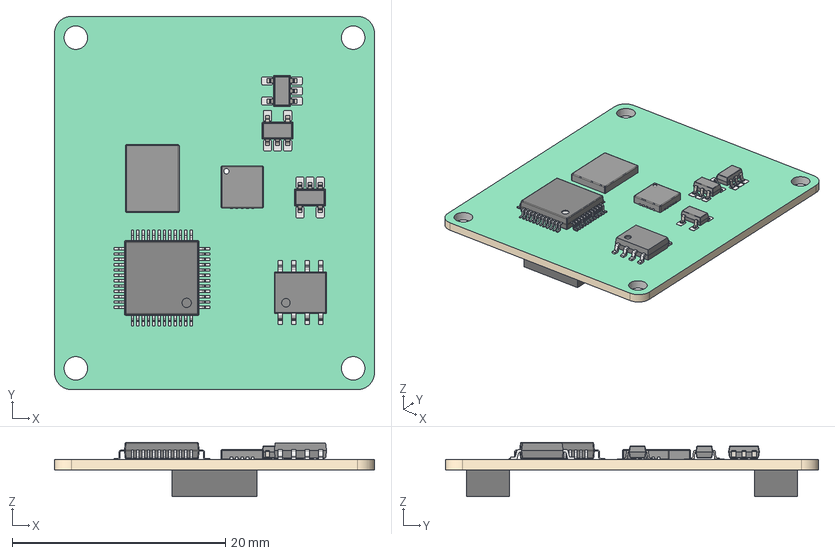
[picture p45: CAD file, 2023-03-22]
CAD Design Files & 3D Models/stp/MR60FDA1.step
30.0 x 35.0 x 5.10 mm
2.0mm Headers (M)
Open_CASCADE_STEP_translator_6.8_13.2.1.step_Varsaylan
Open_CASCADE_STEP_translator_6.8_13.1.step_Varsay lan
Leader.step_Varsaylan x 24
Leader-0.step_Varsaylan x 24
SOIC-8 v1
sot23-5 v3 x 3

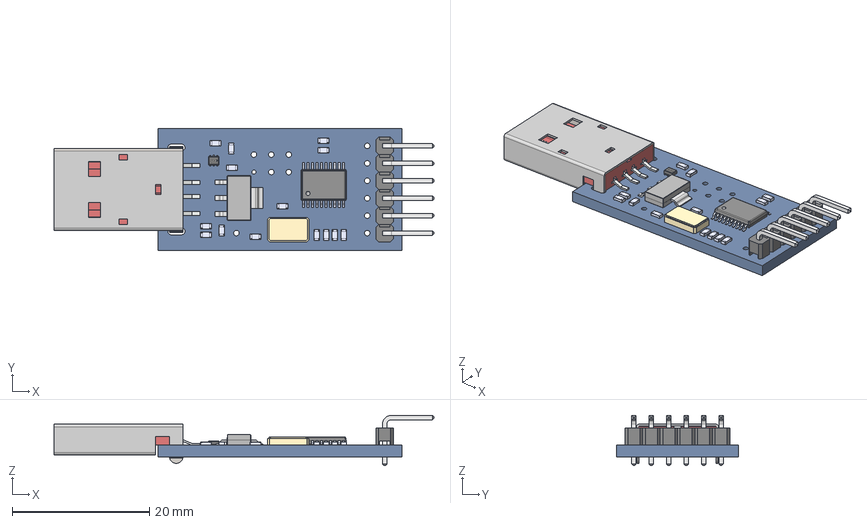
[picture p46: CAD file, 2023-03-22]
CAD Design Files & 3D Models/stp/ftdi-USB-Dongle.step
55.3 x 17.8 x 7.30 mm
STM32F070-minidongle

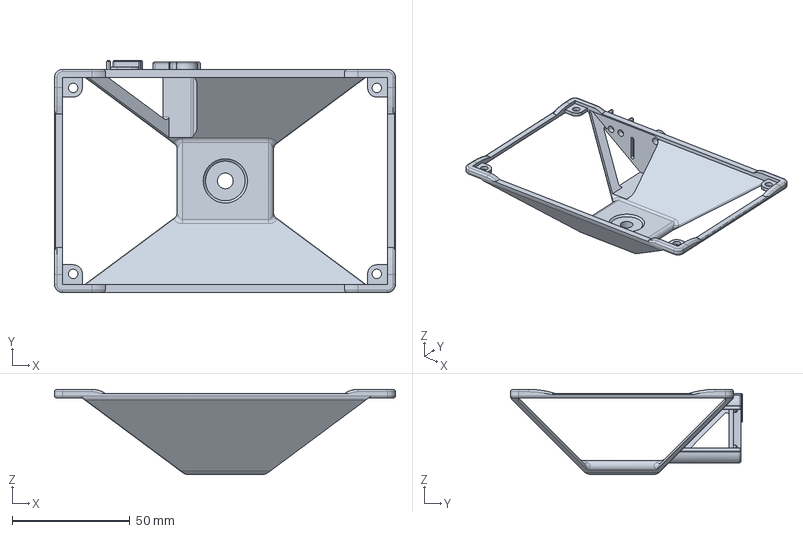
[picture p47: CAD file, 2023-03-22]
CAD Design Files & 3D Models/stp/PYNQ-3D-Printed-Tripod-Mount.step
144.8 x 98.6 x 36.2 mm

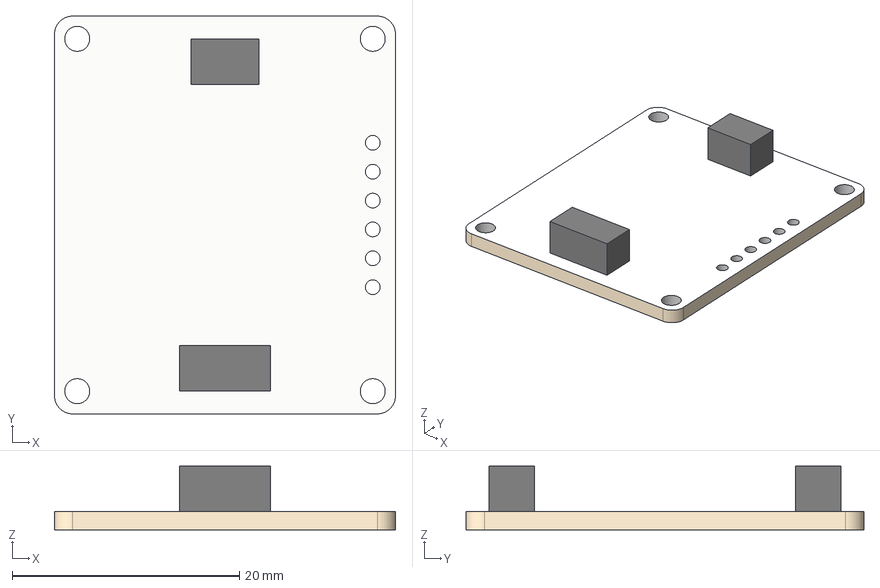
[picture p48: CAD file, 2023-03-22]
CAD Design Files & 3D Models/stp/Custom PCB.step
30.0 x 35.0 x 5.60 mm

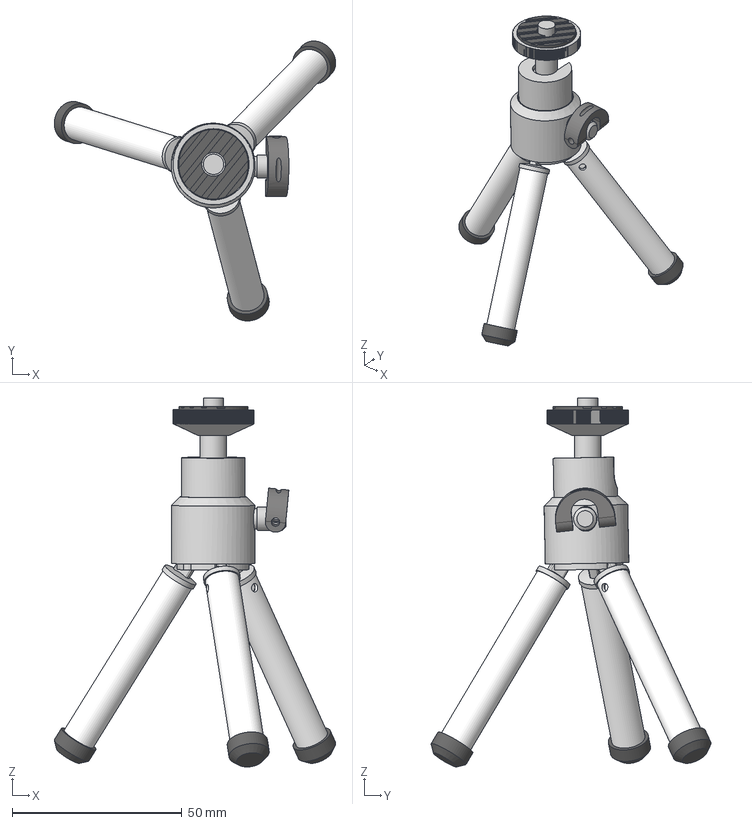
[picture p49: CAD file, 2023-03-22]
CAD Design Files & 3D Models/stp/Small-Tripod.step
83.0 x 82.6 x 108.8 mm
Klemmscheibe
Schlitzscheibe 1 x 2
Sicherungsblech
Exzenterachse
Griff
Kugelgelenkachse
Kugelgelenkhülse
Gehäusehülse
Rändelmutter
Gummiauflage
Kugelgelenkbuchse
DIN 3771 - 2,5 x 1,8 - N - NBR 70(1)
Fußschutz x 3
Fußgelenkstück x 3
Stift x 3
Fußrohr x 3

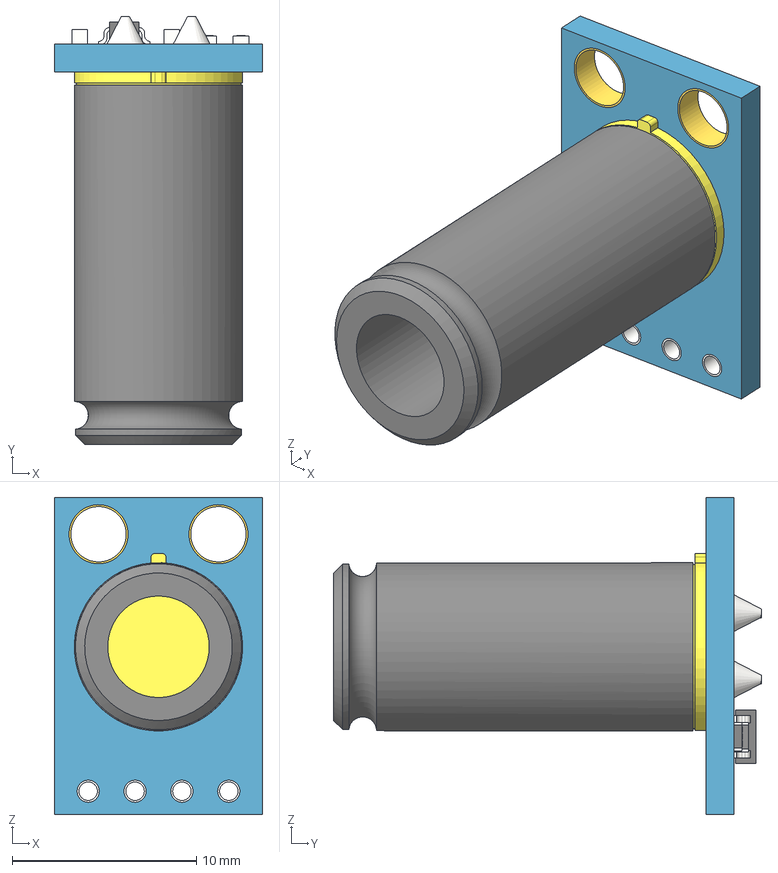
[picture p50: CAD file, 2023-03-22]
CAD Design Files & 3D Models/stp/MLX90614ESF-LongRange_Module v6.step
11.3 x 23.2 x 17.2 mm
module_board
toc-can_soldering
472_smd_resistor1
472_smd_resistor2
capacitor1
capacitor (1)
SOT-23_XC6206
MLX90614xCI_SensorTube v6

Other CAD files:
CAD Design Files & 3D Models/3mf/PYNQ-3D-Printed-Tripod-Mount.3mf
CAD Design Files & 3D Models/f360/Custom PCB.f3d
CAD Design Files & 3D Models/f360/MLX90614ESF-LongRange_Module v6.f3d
CAD Design Files & 3D Models/f360/MR60FDA1.f3d
CAD Design Files & 3D Models/f360/OV2640 v2 v4.f3d
CAD Design Files & 3D Models/f360/PYNQ-3D-Printed-Tripod-Mount.f3d
CAD Design Files & 3D Models/f360/Small-Tripod.f3d
CAD Design Files & 3D Models/f360/USB-Stick-Assembly-MR60FDA1-60GHz-Radar.f3d
CAD Design Files & 3D Models/f360/VL53l1X v8.f3d
CAD Design Files & 3D Models/f360/ftdi-USB-Dongle.f3d
CAD Design Files & 3D Models/stl/PYNQ-3D-Printed-Tripod-Mount.stl

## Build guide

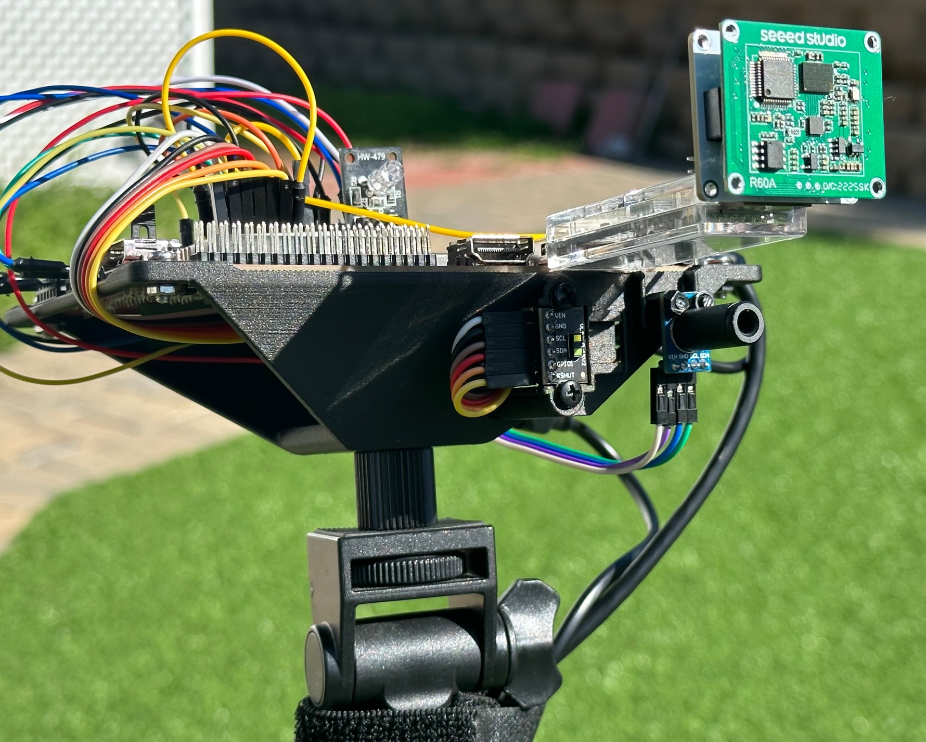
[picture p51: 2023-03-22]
Docs/Images/Final-Project-Assembled/sensors-macro.jpg

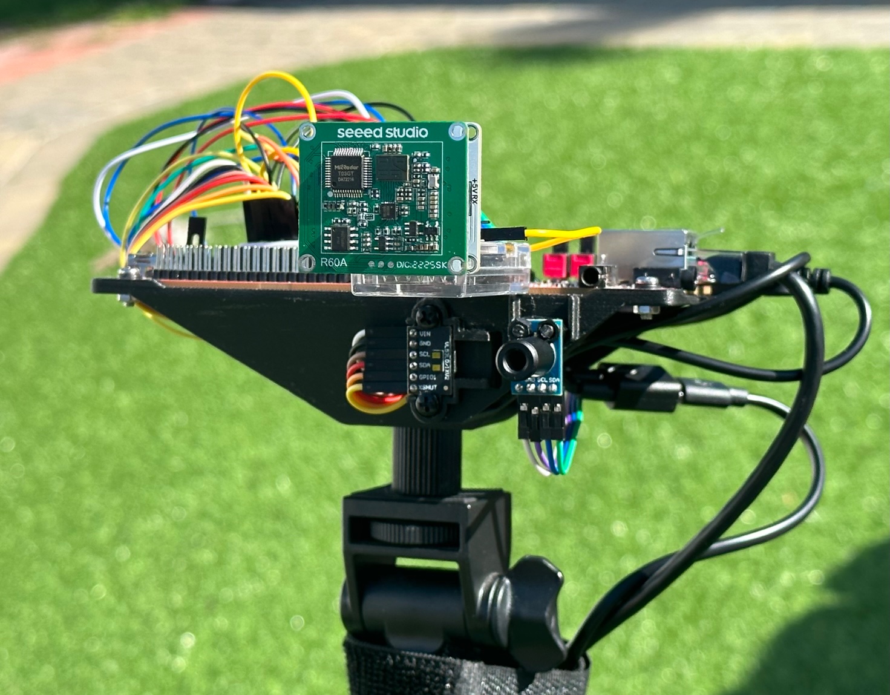
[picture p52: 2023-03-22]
Docs/Images/Final-Project-Assembled/front.jpg

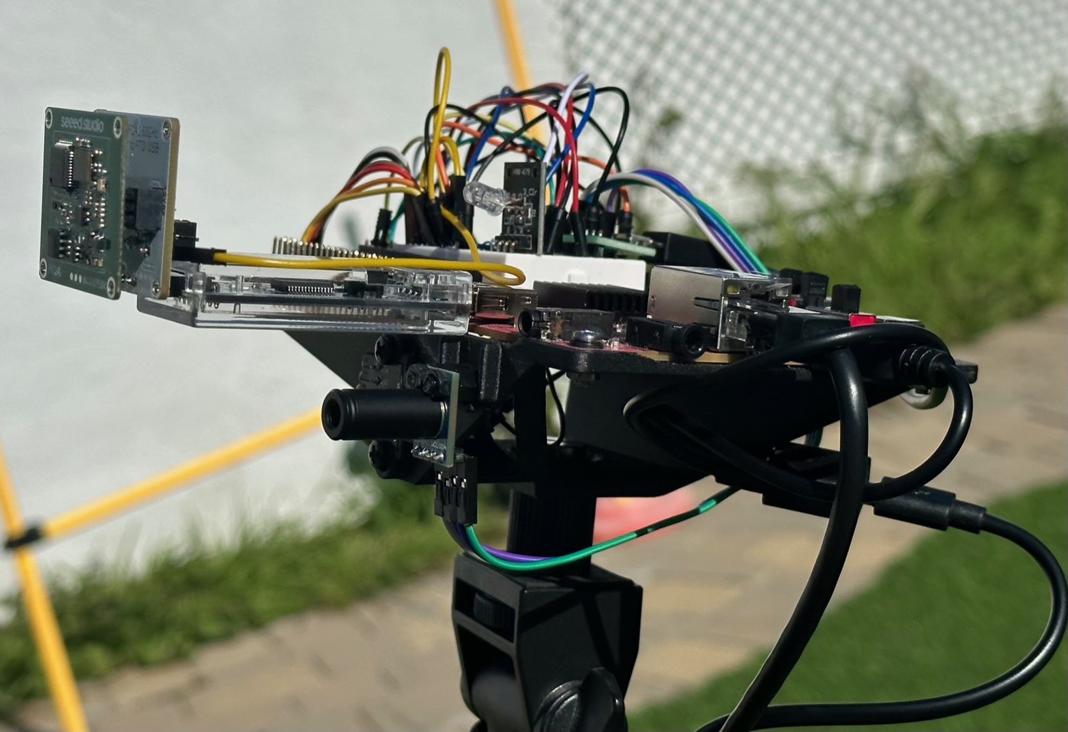
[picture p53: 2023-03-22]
Docs/Images/Final-Project-Assembled/side.jpg

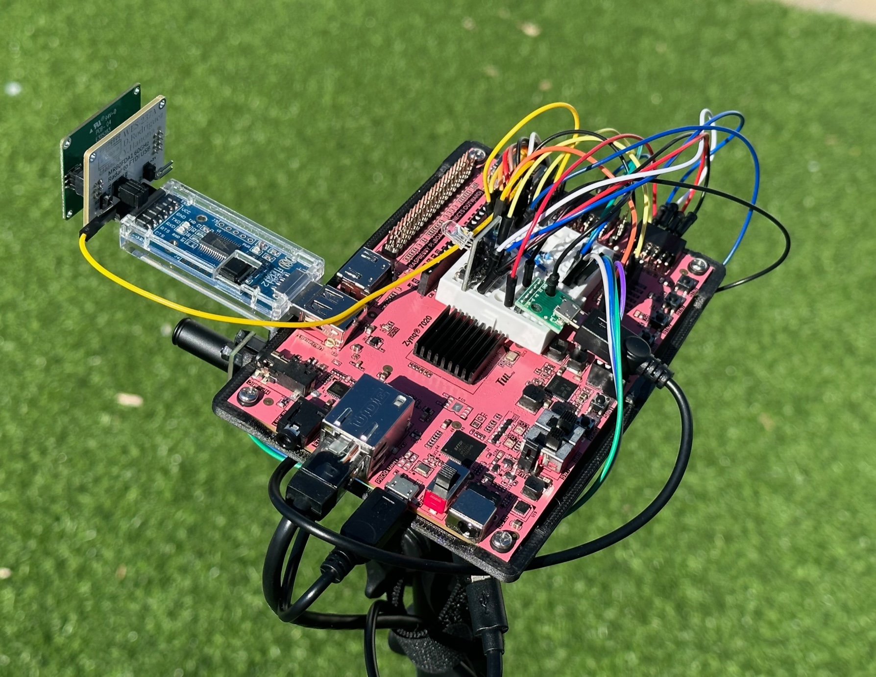
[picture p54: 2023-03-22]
Docs/Images/Final-Project-Assembled/iso-upper.jpg

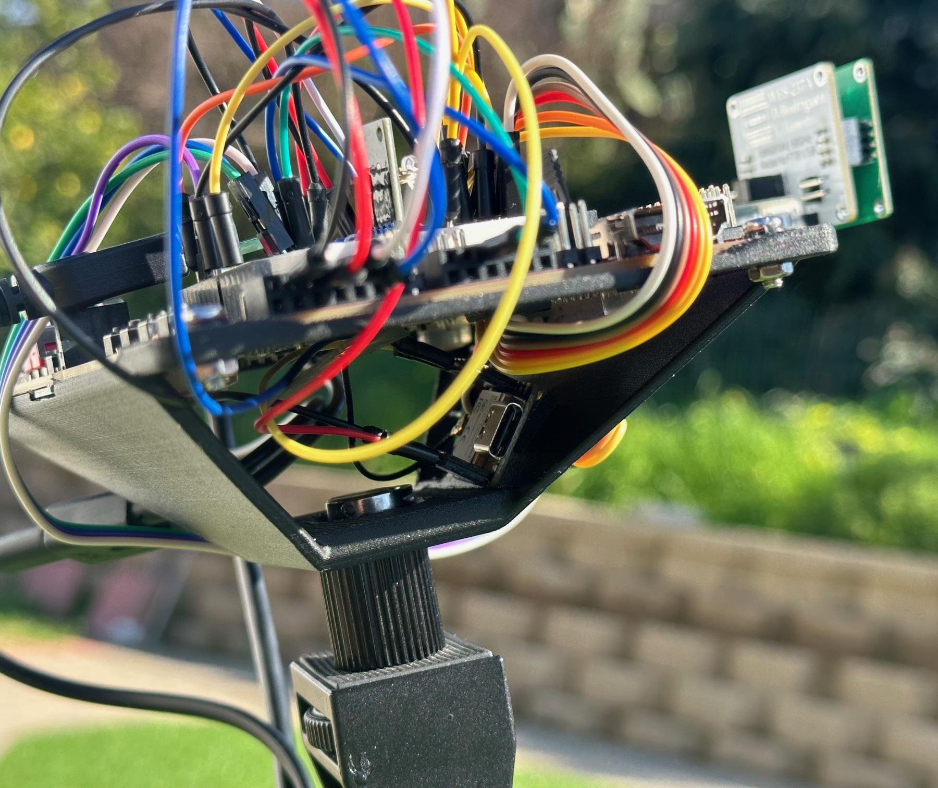
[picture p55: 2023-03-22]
Docs/Images/Final-Project-Assembled/esp-internal.jpg

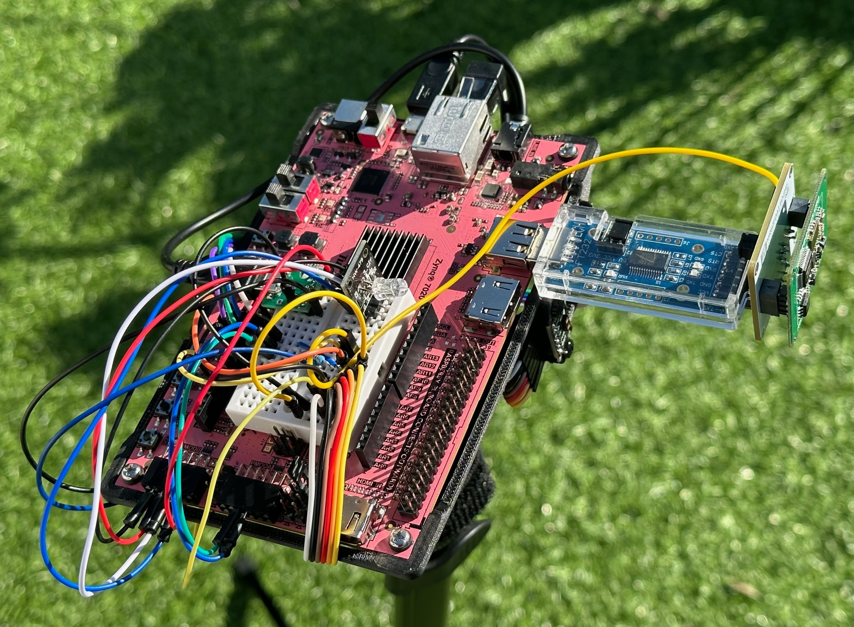
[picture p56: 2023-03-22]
Docs/Images/Final-Project-Assembled/top.jpg

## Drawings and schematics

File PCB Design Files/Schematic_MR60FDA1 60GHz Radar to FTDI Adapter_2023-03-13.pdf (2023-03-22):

# MR60FDA1 60GHz Radar Sensor to FTDI USB Serial Adapter

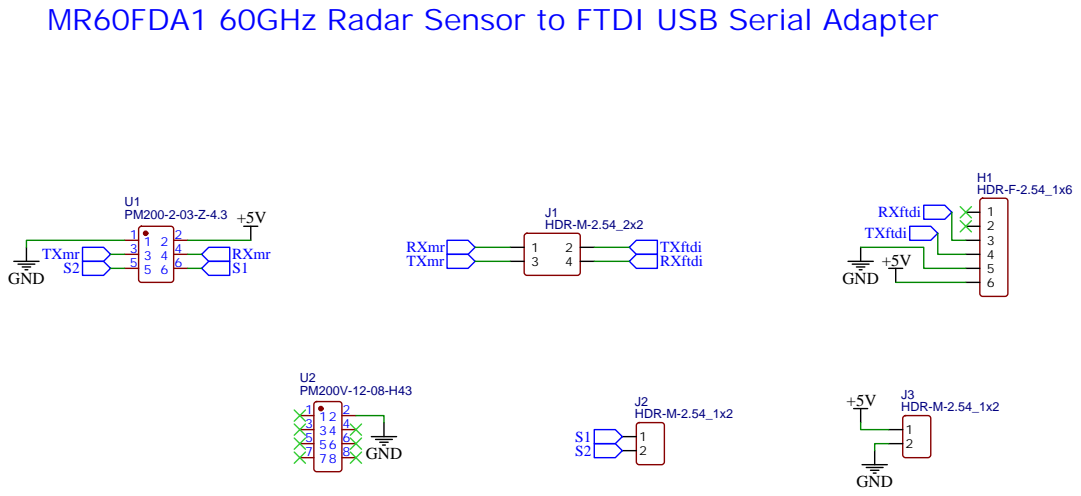
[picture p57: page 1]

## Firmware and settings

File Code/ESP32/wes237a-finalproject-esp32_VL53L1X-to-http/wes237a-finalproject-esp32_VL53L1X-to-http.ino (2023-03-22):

// WES237A Final Project - ESP32: VL53L1X to http POST
// David Rodriguez
// March 2023


#include <WiFi.h>
#include <HTTPClient.h>
#include "SparkFun_VL53L1X.h"

const char* ssid = "ssid";
const char* password = "password";

// AWS Public DNS Domain name containing ToF http URL path
const char* serverName = "http://ec2-35-90-59-237.us-west-2.compute.amazonaws.com:1880/tof";

unsigned long lastTime = 0;
unsigned long timerDelay = 1000; // 1 sec. timer delay
String ToF;

SFEVL53L1X distanceSensor;

void setup() {
  Wire.begin();
  Serial.begin(115200);
  Serial.println("WES237A Final Project - ESP32 VL53L1X Sensor Node");

  if (distanceSensor.begin() != 0) // begin returns 0 from successful init{
    Serial.println("Sensor failed to begin. Please check wiring and restart.");
    while (1)
      ;
  }
  Serial.println("Distance Sensor Online");

  WiFi.begin(ssid, password);
  Serial.println("Connecting to WiFi");
  while(WiFi.status() != WL_CONNECTED) {
    delay(500);
    Serial.print(".");
  }
  Serial.println("");
  Serial.print("Connected to WiFi network with IP Address: ");
  Serial.println(WiFi.localIP());
}

void loop() {
  //Send an HTTP POST request after every timer delay
  if ((millis() - lastTime) > timerDelay) {
    // Check WiFi connection status
    if(WiFi.status()== WL_CONNECTED) {
      WiFiClient client;
      HTTPClient http;
    
      // Initiate connection to AWS Server
      http.begin(client, serverName);
      
      distanceSensor.startRanging(); // Write configuration bytes to initiate measurement
      while (!distanceSensor.checkForDataReady()) {
        delay(1);
      }

      int distance = distanceSensor.getDistance(); // Get the sensor measurement result
      distanceSensor.clearInterrupt();
      distanceSensor.stopRanging();
    
      Serial.print("Distance(mm): ");
      Serial.print(distance);

      ToF = String(distance);
      
      // HTTP POST request with Content type: text/plain
      http.addHeader("Content-Type", "text/plain");
      int httpResponseCode = http.POST(ToF);
     
      Serial.print("HTTP Response code: ");
      Serial.println(httpResponseCode);
        
      // Free up ESP32 Resources
      http.end();
    }
    else {
      Serial.println("WiFi Disconnected");
    }
    lastTime = millis();
  }
}
